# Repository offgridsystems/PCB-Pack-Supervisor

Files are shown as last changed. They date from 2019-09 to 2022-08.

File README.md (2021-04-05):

# Pack Supervisor
### Hardware Files For The 127x97mm Pack Supervisor Board
These are the printed circuit board (PCB) files, CAD files, specification sheets and all technical drawings needed to make the DKblock Pack Supervisor board. Note that the bill of materials (BOM) and other technical documents can be opened in [OpenOffice](https://www.openoffice.org) format and PCB files are in [EAGLE](https://www.autodesk.com/products/eagle/overview) format but they can also be opened and edited in the open source Kicad program.

#### VERSIONS
- Rev A - Revision A (retired name of board is Supervisor LV Rev A)  is a fully tested board, put into  production on a 72VDC electric scooter named Fido, and a 150VDC VW bug conversion.
- Rev B - Revision B are design files that make improvements on the A version, and change the board name to Pack Supervisor 97x127mm Rev B, but *Rev B has neither not been built nor tested in the real world*. Note that most of the changes are minor and are simple tweaks to improve performance or reliability.
- Ver 2 - NOT RELEASED but these are improvements to cost, performance, and reliability.

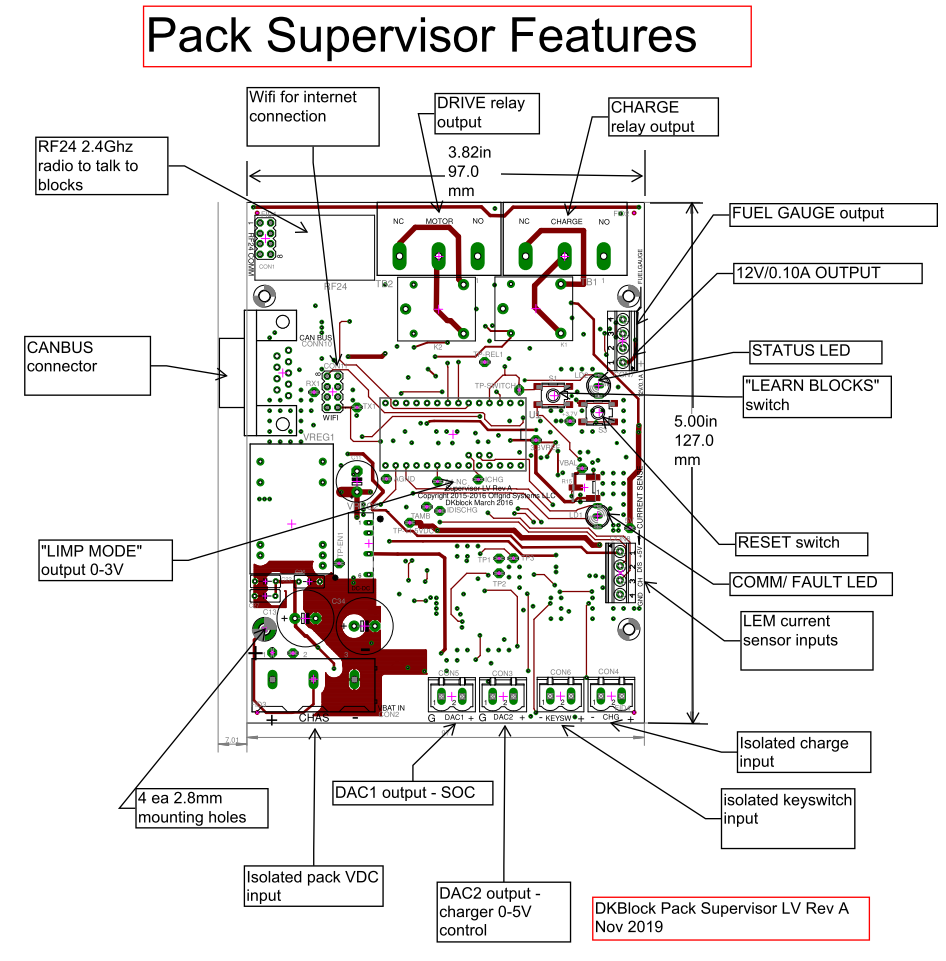
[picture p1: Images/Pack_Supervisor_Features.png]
Pack Supervisor Features


Pack Supervisor Top RevA

Pack Supervisor Bottom RevA

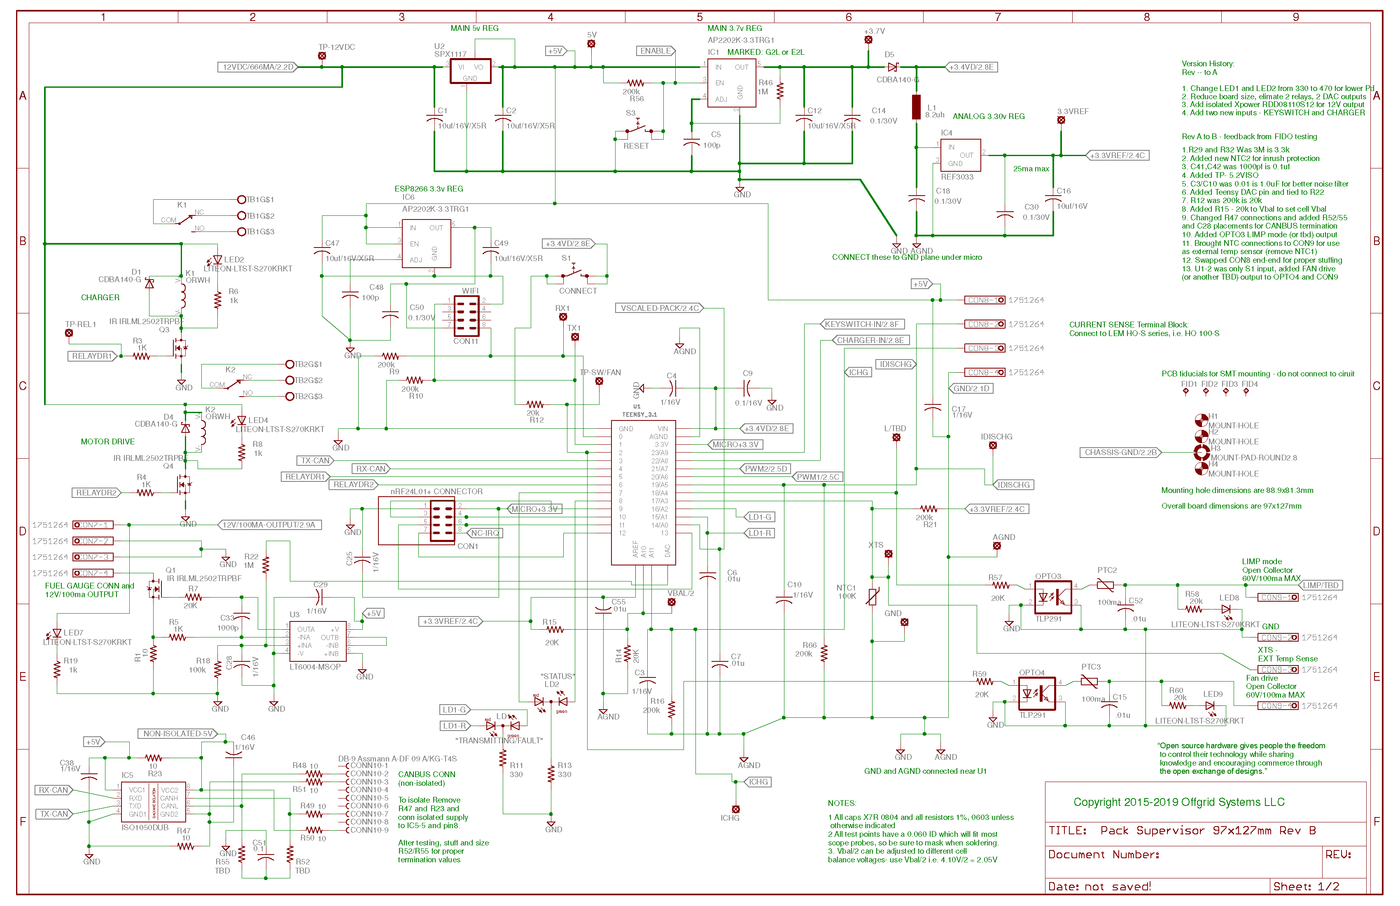
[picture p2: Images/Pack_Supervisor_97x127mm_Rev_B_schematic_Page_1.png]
Pack Supervisor Schematic 1


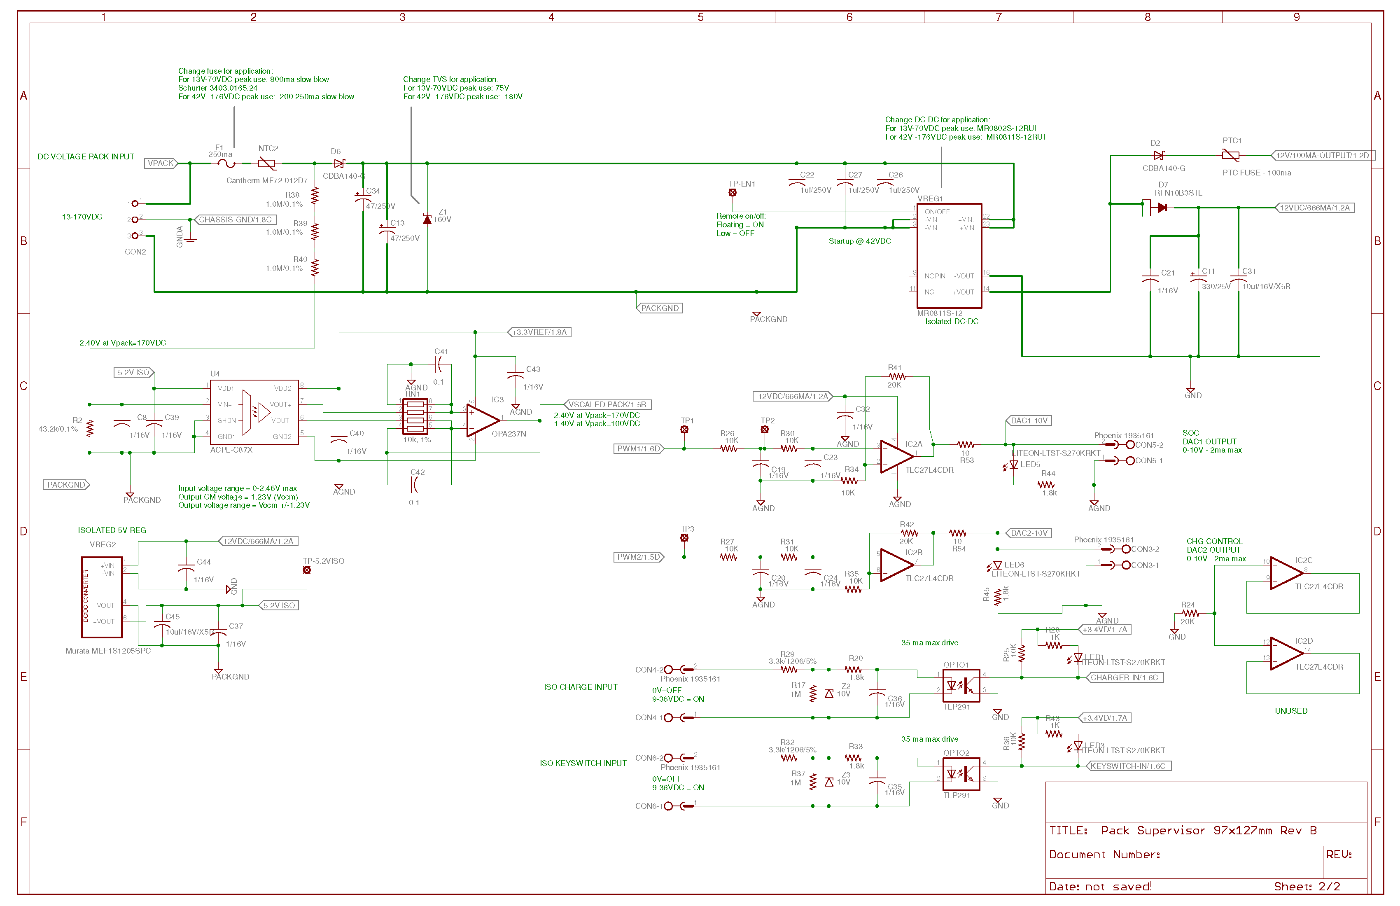
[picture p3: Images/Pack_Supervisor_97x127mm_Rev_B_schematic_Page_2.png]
Pack Supervisor Schematic 1


New V2 radio (replaces RF24 board and requires new Supervisor V2 firmware)



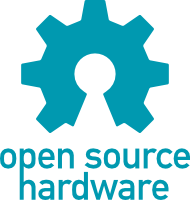
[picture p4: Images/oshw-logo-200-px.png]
Open Hardware


All DKblock software and hardware is released as open source hardware (OSHW) as defined by the OSHWA: https://www.oshwa.org/definition/ and under the JSON license defined at https://www.json.org/license.html

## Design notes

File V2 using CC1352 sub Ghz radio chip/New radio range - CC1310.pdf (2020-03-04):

Sheet1

Page 1

## New radio range – cc1310 using two CC1310 Lauchpads and TI SmartRF studio

Test conditions, Cow hill lab, TX/RX set at 50kbps, 2-GFSK, 25kHz deviation for most of testing, also tested at 500kBps,

### 175khz dev with no real changes, both CC1310 Lauchpad units had low cost PCB antenna

Freq (Mhz) TX power dBm RX @1 meter range(dBm) 9 meter range | notes
750 | 14 | -32 | -52 | all RX is at 0.0% PER and 0.00% Bit error rate and tested at 50k-500kBPS no discernable receive signal loss
850 -20
868 | | -20 | -49
950 -32
1000 | | -39 | -70 | Would go from -70 to -80 by just walking around room between TX and RX units
1100 -50
868 | -10 | | -72
868 OFF | | | -93

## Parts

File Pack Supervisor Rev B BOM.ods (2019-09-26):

Pack Supervisor BOM Rev B |  |  | Offgrid Systems | 05/12/16 | Rev --7/1/2015 for changes from assy feedback, Rev A 5/12/2016 new smaller board with more features – built 10 pcs at TASC in seattle
 |  |  |  | 04/17/17 | Rev B -Changes based on testing Rev A
 |  |  |  |  |  |  |  |  |  | Circuit ok
x=Offgrid Provided |  |  | DNS = Do not stuff (on VREG1 please mask PCB pins) |  |  |  |  |  |  | New part size
 |  |  |  |  |  |  |  |  |  | Double check BOM
 | Qty | Value | Device | Package | Parts | Description | 100PCPRICE | Ext 100 | MPN (all in stock at Digikey) | Double check BOM | PIN-HEADER | Alternative PN
 | 7 | STATUS | LEDSMT | 2 SMD | LED1, LED2, LED3, LED4, LED5, LED6, LED7 | LED YELLOW CLEAR 0603 R/A SMD | 0.103 | 0.721 | LiteOn LTST-S270KSKT | x
 | 2 | STATUS & TRANSMITTING | Radial - 3 Lead | Radial 3 | LD1, LD2 | LED 5MM BI-COLOR RED/GRN DIFF | 0.2 | 0.4 | Kingbright WP59EGC
 |  |  |  |  |  |  |  | 0
 | 9 | 10 | R-US_R0603 | R0603 | R1, R23, R47, R48, R49, R50, R51, R53, R54 | RES SMD 10 OHM 1% 1/10W 0603 | 0.018 | 0.162 | Bourns CR0603-FX-10R0ELF
 | 2 | 330 | R-US_R0603 | R0603 | R11, R13 | RES SMD 330 OHM 1% 1/10W 0603 | 0.0187 | 0.0374 | Bourns CR0603-FX-3300ELF
 | 8 | 1k | R-US_R0603 | R0603 | R3, R4, R5, R6, R8, R19, R28, R43 | RES SMD 1K OHM 1% 1/10W 0603 | 0.018 | 0.144 | Bourns CR0603-FX-1001ELF
 | 4 | 1.8k | R-US_R0603 | R0603 | R20, R33, R44, R45 | RES SMD 1.8K OHM 1% 1/10W 0603 | 0.018 | 0.072 | CR0603-FX-1801ELF
 | 8 | 10k | R-US_R0603 | R0603 | R25, R26, R27, R30, R31, R34, R35, R36 | RES SMD 10K OHM 1% 1/10W 0603 | 0.018 | 0.144 | Bourns CR0603-FX-1002ELF
 | 5 | 20k | R-US_R0603 | R0603 | R7, R14, R24, R41, R42 | RES SMD 20K OHM 1% 1/10W 0603 | 0.018 | 0.09 | Bourns CR0603-FX-2002ELF
 | 1 | 43.2k/0.1% | R-US_R0603 | R0603 | R2 | RES SMD 43.2KOHM 0.1% 1/10W 0603 | 0.192 | 0.192 | Panasonic ERA-3AEB4322V
 | 1 | 100K | R-US_R0603 | R0603 | R18 | RES SMD 100K OHM 1% 1/10W 0603 | 0.018 | 0.018 | Bourns CR0603-FX-1003ELF
 | 7 | 200k | R-US_R0603 | R0603 | R9, R10, R12, R16, R21, R56, R66 | RES SMD 200K OHM 1% 1/10W 0603 | 0.018 | 0.126 | Bourns CR0603-FX-2003ELF
 | 4 | 1M | R-US_R1206 | R1206 | R17, R22, R37, R46 | RES SMD 1M OHM 1% 1/10W 0603 | 0.0187 | 0.0748 | Bourns CR0603-FX-1004ELF
 | 3 | 1.0M/0.1% | R0805 | R0805 | R38, R39, R40 | RES SMD 1M OHM 0.1% 1/8W 0805 | 0.192 | 0.576 | Panasonic ERA-6AEB105V
 | 2 | 3M/1206/5% | R-US_R1206 | R1206 | R29, R32 | RES SMD 3M OHM 5% 1/4W 1206 | 0.015 | 0.03 | Panasonic ERJ-8GEYJ305V
 | 1 | 10k | 1206 | 1206 | RN1 | RES ARRAY 4 RES 10K OHM 1206 5% | 0.023 | 0.023 | Yageo TC164-FR-0710KL | x |  | Yageo TC164-FR-0710KL
 | 2 | 100p | C-USC0805K | C0805K | C5, C48 | CAP CER 100PF 50V 10% X7R 0805 | 0.079 | 0.158 | Kemet C0805C101K5RACTU
 | 1 | 1000p | C-USC0805K | C0805K | C33 | CAP CER 1000PF 50V 10% X7R 0805 | 0.017 | 0.017 | Kemet C0805C102K5RACTU
 | 6 | .01u | c0805 | c0805 | C3, C6, C7, C10, C15, C55 | CAP CER 10000PF 50V 10% X7R 0805 | 0.015 | 0.09 | Kemet C0805C103K5RACTU
 | 7 | 0.1/50V | c0805 | c0805 | C14, C18, C9, C30, C50, C41, C42 | CAP CER 0.1UF 50V 10% X7R 0805 | 0.022 | 0.154 | Kemet C0805C104K5RACTU
 | 21 | 1/16V | C-USC0805K | C0805K | C4, C8, C17, C19, C20, C21, C23, C24, C25, C28, CONT. BELOW | CAP CER 1UF 16V 10% X7R 0805 | 0.04 | 0.84 | Kemet C0805C105K4RACTU
 |  |  |  |  | C29, C32, C35, C36, C37, C38, C39, C40, C43, C44, C46 |  |  | 0
 | 3 | 1uf/250V | Radial 2 lead .2in | Radial 2 | C22, C26, C27 | CAP CER 1UF 20% 250V X7R Thru hole | 0.833 | 2.499 | MURATA RDER72E105MUB1H03B | x
 | 8 | 10uf/16V/X5R | C-USC0805K | C0805K | C1, C2, C12, C16, C31, C45, C47, C49 | CAP CER 10UF 16V 20% X5R 0805 | 0.062 | 0.496 | Murata GRM21BR61C106ME15L
 | 2 | 47/250V | CPOL-USE5-13 | E5-13 | C13, C34 | CAP ALUM 47UF 250V 20% RADIAL | 0.508 | 1.016 | PANASONIC ECA-2EM470
 | 1 | 330uf | Radial 2 lead | 0.315" Dia | C11 | CAP ALUM 330UF 25V 20% Radial | 0.216 | 0.216 | United Chemicon EKY-250ELL331MJC5S
 |  |  |  |  |  |  |  | 0
 | 1 | 250ma SB | UMT250 | UMT250 | F1 | FUSE BRD MNT 250MA 250VAC 125VDC | 0.51 | 0.51 | Schurter 3403.0160.11 | x |  | Schurter 3403.0159 or Schurter 3403.0161
 | 1 | 100ma PTC fuse | 0603 | 0603 | PTC1 | PTC RESETTBLE 0.10A 15V CHIP 0603 | 0.11 | 0.11 | Bel Fuse 0ZCM0010FF2G
 | 1 | 1A 12 ohm NTC | Power NTC | 9mm leaded | NTC2 | ICL, 12 ohm, 20% 1A 9mm dia, leaded | 0.22 | 0.22 | Cantherm MF72-012D7
 |  |  |  |  |  |  |  | 0
 | 1 | 100K | NTC-MURATA-NCP18WF104J03RB | 0603 | NTC1 | THERMISTOR NTC 100K OHM 5% 0603 | 0.106 | 0.106 | MURATA NCP18WF104J03RB
 |  |  |  |  |  |  |  | 0
 | 1 | 8.2uh | SM-1206 | SM-1206 | L1 | FIXED IND 8.2UH 25MA 800 MOHM | 0.22 | 0.22 | Abracon AIML-1206-8R2K-T
 |  |  |  |  |  |  |  | 0
 | 1 | RFN10B3STL | RFN10B3STL | TO252-FATPADS | D7 | DIODE GEN PURP 350V 10A CPD | 0.59 | 0.59 | ROHM RFN10B3STL
 | 2 | ZENER – 10V | SOT23 | SOT23 | Z2, Z3 | DIODE ZENER 10V 225MW SOT23-3 | 0.084 | 0.168 | ON SEMI SZBZX84C10LT1G | x
 | 5 | CDBA140-G | CDBA140-G | DO214AC | D1, D2, D4, D5, D6 | DIODE SCHOTTKY 40V 1A DO214AC | 0.187 | 0.935 | Comchip CDBA140-G
 | 1 | ZENER – 160V | SMB | SMB | Z1 | DIODE ZENER 160V 3W SMB | 0.218 | 0.218 | ON SEMI 1SMB5954BT3G | x
 |  |  |  |  |  |  |  | 0
 | 2 | CONNECT and RESET | PTS645 | PTS645 | S1, S3 | SWITCH TACTILE SPST-NO 0.05A 12V | 0.129 | 0.258 | C&k PTS645SM43SMTR92 LFS
 |  |  |  |  |  |  |  | 0
 | 3 | IRLML2502TRPBF | SOT23 | SOT23 | Q1, Q3, Q4 | MOSFET N-CH 20V 4.2A SOT-23 | 0.22 | 0.66 | IR IRLML2502TRPBF
 |  |  |  |  |  |  |  | 0
 | 2 | Current sensors & Fuel Gauge connectors | 1751264 | 1751264 | CON7, CON8 | CONN TERM BLOCK 4POS 3.5MM 300V 10A | 2 | 4 | Phoenix 1751264
 | 2 | TE-5-1437652-4 | TE-5-1437652-4 | TE-5-1437652-4 | TB1, TB2 | Connector Barrier Block Strip 3 Circuit 0.375" 300V 25A | 1.16 | 2.32 | TE 5-1437652-4
 | 4 | Phoenix Term block | 2 Pos 0.197” pitch |  | CON3, CON4, CON5, CON6 | TERM BLOCK PCB 2POS 5.0MM GREEN | 0.327 | 1.308 | Phoenix 1935161 | x
 | 1 | TYCO-796739-3 | TYCO-796739-3 | TYCO-796739-3 | CON2 | TERM BLOCK 3POS SIDE ENT 9.52MM | 3.22 | 3.22 | TE 796739-3
 | 1 | WIFI | DUAL ROW 0.1X0.1 |  | CON11 | 8 Position Header Connector 0.100" 2x4 | 0.52 | 0.52 | Sullins PPPC042LFBN-RC | x
 | 1 | CON1 socket for RF24 | Female socket header | female socket | CON1 | 8 Position Header Connector 0.100" 2x4 | 0.52 | 0.52 | Sullins PPPC042LFBN-RC | x
 |  |  |  |  |  |  |  | 0
 | 1 | ACPL-C87X | STRETCH-SO8 | STRETCH-SO8 | U4 | IC OPAMP ISOLATION 100KHZ 8SO | 5.71 | 5.71 | Avago ACPL-C87B-000E | x
 | 2 | TLP291 | MINI FLAT 4 | MINI FLAT 4 | OPTO1, OPTO2 | OPTOISOLATOR 3.75KV TRANS 4-SO | 0.332 | 0.664 | Toshiba TLP291(BLL-TP,SE | x
 | 1 | REF3033 | SOT23 | SOT23 | IC4 | IC VREF SERIES 3.3V SOT23-3 | 1.18 | 1.18 | TI REF3033AIDBZR | x
 | 1 | MEF1S1205 | 7-SIP Module (4 Leads) |  | VREG2 | DC/DC CONVERTER 5V 1W SIP | 4.6 | 4.6 | Murata MEF1S1205SPC | x
 | 1 | OPA237 | SOT23-5 | SOT23-5 | IC3 | IC OPAMP GP 1.5MHZ SOT23-5 | 1.06 | 1.06 | TI OPA237NA/3K | x
 | 1 | LT6004 | MSOP | MSOP | U3 | IC OPAMP GP 3KHZ RRO 8MSOP | 1.3 | 1.3 | LTC LT6004CMS8 | x
 | 1 | ISO1050 | 8sop |  | IC5 | IC TXRX CAN 5V 8SOP | 3.43 | 3.43 | TI ISO1050DUBR | x
 | 2 | AP2202K-3.3TRG1 | MIC5205 | SOT23-5 | IC1, IC6 | IC REG LDO 3.3V 0.15A SOT25 | 0.19 | 0.38 | Diodes AP2202K-3.3TRG1
 | 1 | SPX1117 | SPX1117 | SOT223 | U2 | IC REG LDO 5V 0.8A SOT223 | 0.26 | 0.26 | Exar SPX1117M3-L-5-0/TR
 | 1 | TLC27L4CDR | TLC27L4CDR | SO14 | IC2 | IC OPAMP Low IQ RRO 14SOIC | 0.63 | 0.63 | TI TLC27L4CDR
 | 1 | U1 socket – stuff in all 31 positions of U1 |  |  | IC1 – all 31 positions | Connector Socket 60 Position 0.100" (2.54mm) Gold Through Hole |  | 0 | Precidip 315-87-160-41-003101 (need 6 ea for every 10 PCB)
x | 1 | MR0811s-12 | Leaded CAN |  | VREG1 | Ultra-wide input DC/DC DIP case 12V outpuy | 17 | 17 | MicroPower Direct MR0811S-12RUI |  |  | Xppower RDD08110S12
 | 2 | ORWH | ORWH | ORWH | K1, K2 | RELAY GEN PURPOSE SPDT 10A 12V 277V/28VDC switch | 0.653 | 1.306 | TE 1461069-5 |  |  | TE ORWH-SH-112D,N000
x | 1 | DSUB-9 | Dsub |  | CONN10 | 9 Pos D-Sub Male Pins Connector, TH, RA Solder | 0.56 | 0.56 | ASSMANN A-DS 09 A/KG-T4S
 | 1 | PCB |  |  |  | PCB, Supervisor LV Rev A | 5 | 5 | Offgrid Supervisor LV Rev A PCB
 |  |  |  |  |  | total dk part cost |  | 67.2592
 |  | Note to PCB Assembly house - DO NOT STUFF these parts – they will be added by hand after PCB assembly phase
x | 1 | Teensy 3.1 without pins | TEENSY_3.0-DIP+ANALOG | TEENSY_3.0-DIP+ANALOG | U1 | Do NOT STUFF – U1 only stuff socket | 15 | #VALUE! | OshPark Teensy 3.1 or Addcore Teensy 3.1
x | 1 | Addicore nRF24l01+ | RF24 board |  | CON1 transceiver | nRF24l01 2.4Mhz transceiver | 1 |  | Addicore nRF24l01+
 | 4 | standoff |  |  |  | BRD SPT REST MNT SNAP LOCK 3/16" |  |  | Keystone 9056
 | 1 for every 2 PCBs |  |  |  | U1 Teensy pins for sockets – solder onto Teensy board | Precision pins 0.018 dia for socketizing |  |  | Mill max 342-10-164-00-591000

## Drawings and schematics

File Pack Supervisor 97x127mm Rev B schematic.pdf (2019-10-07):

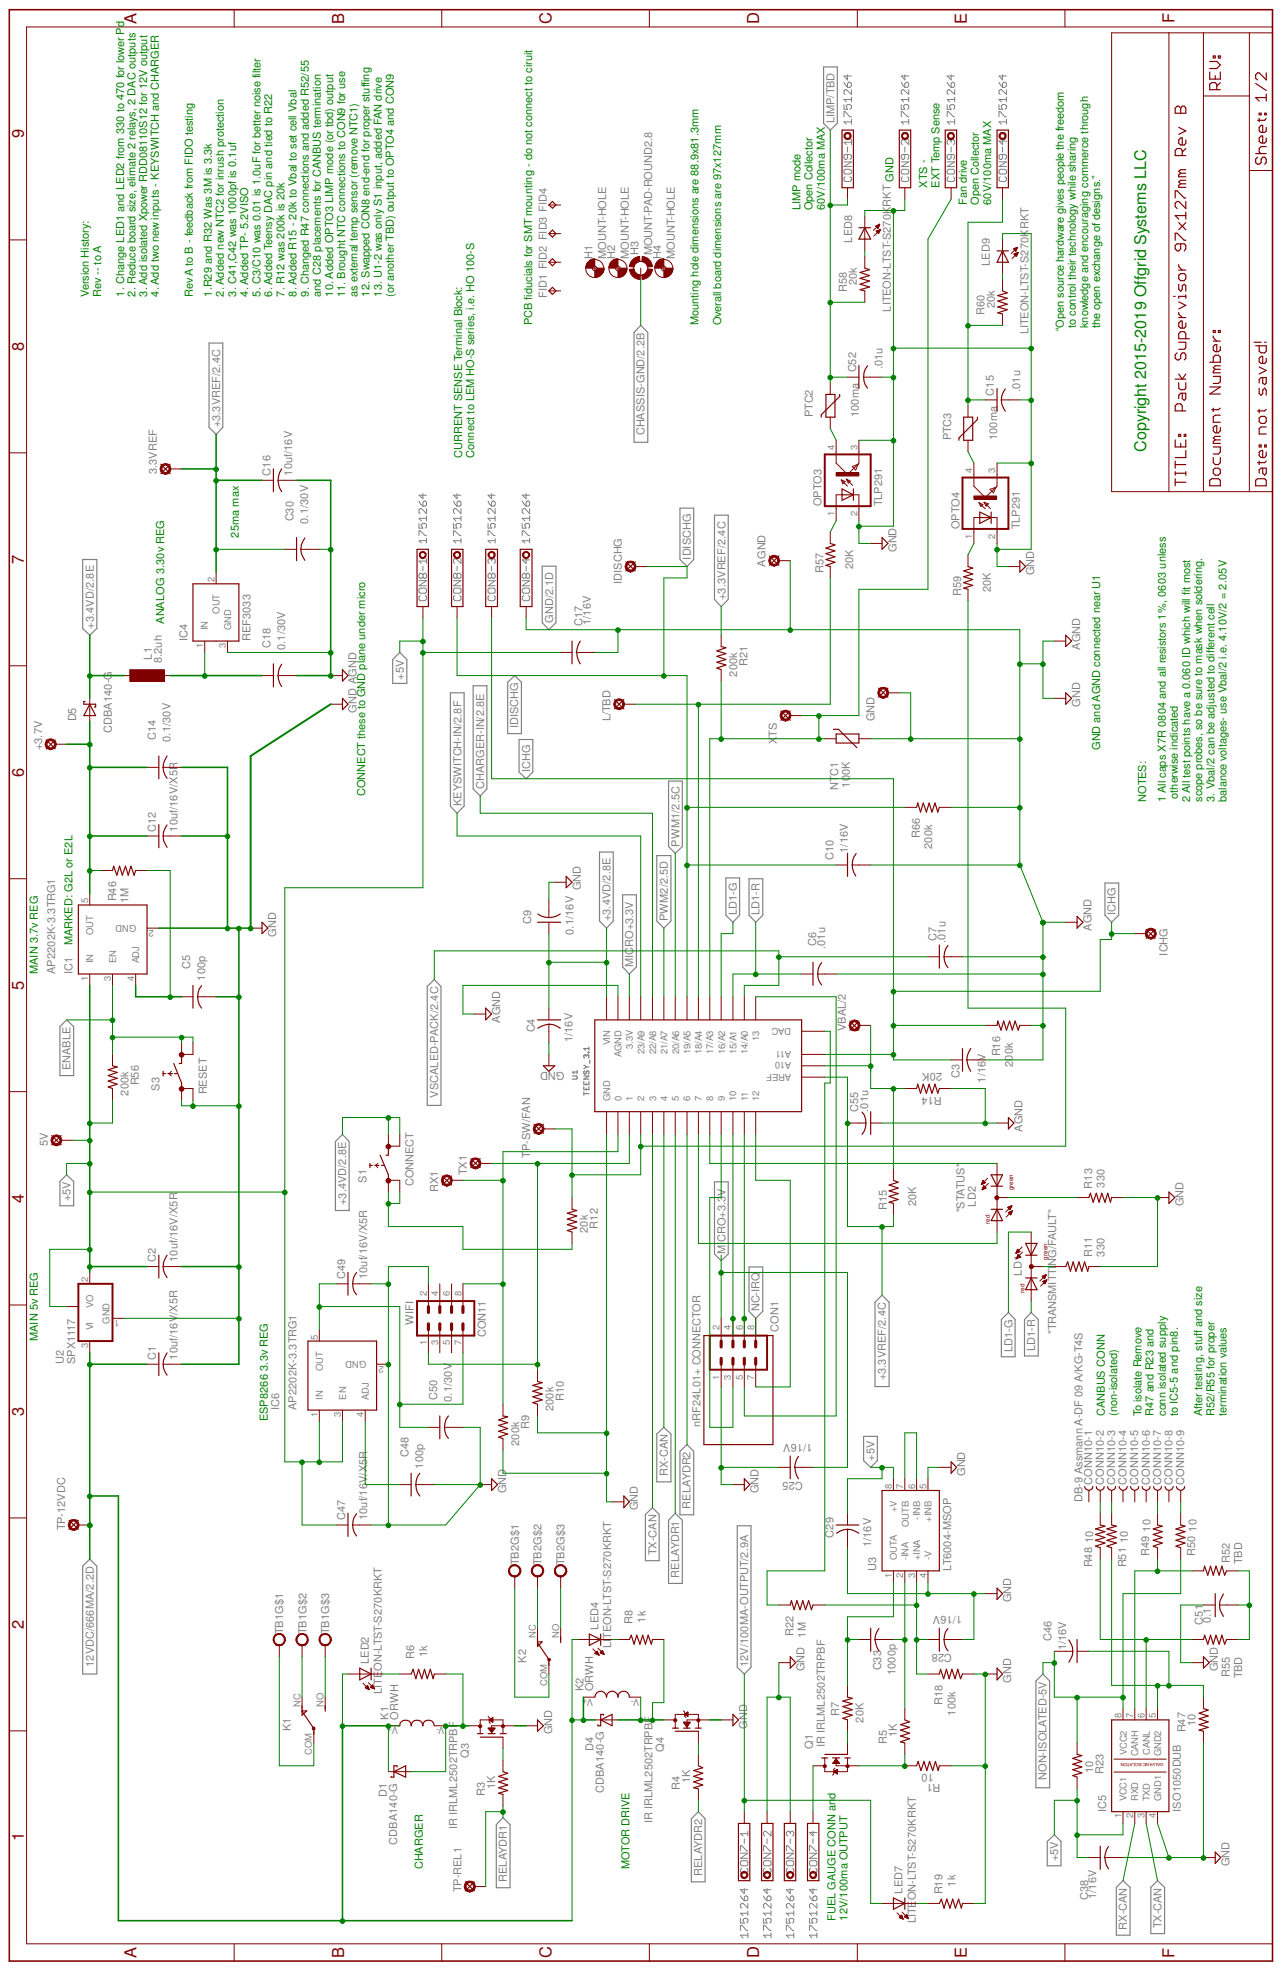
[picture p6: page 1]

1. Change LED1 and LED2 from 330 to 470 for lower Pd

2. Reduce board size, elimate 2 relays, 2 DAC outputs

3. Add isolated Xpower RDD08110S12 for 12V output

4. Add two new inputs - KEYSWITCH and CHARGER

PCB fiducials for SMT mounting - do not connect to ciruit

5. C3/C10 was 0.01 is 1.0uF for better noise filter

9. Changed R47 connections and added R52/55

12. Swapped CON8 end-end for proper stuffing

and C28 placements for CANBUS termination

10. Added OPTO3 LIMP mode (or tbd) output

11. Brought NTC connections to CON9 for use

13. U1-2 was only S1 input, added FAN drive

(or another TBD) output to OPTO4 and CON9

6. Added Teensy DAC pin and tied to R22

8. Added R15 - 20k to Vbal to set cell Vbal

“Open source hardware gives people the freedom

Rev A to B - feedback from FIDO testing

2. Added new NTC2 for inrush protection

as external temp sensor (remove NTC1)

Mounting hole dimensions are 88.9x81.3mm

knowledge and encouraging commerce through

Overall board dimensions are 97x127mm

to control their technology while sharing

the open exchange of designs.”

Connect to LEM HO-S series, i.e. HO 100-S

CURRENT SENSE Terminal Block:

1 All caps X7R 0804 and all resistors 1%, 0603 unless

2 All test points have a 0.060 ID which will fit most

scope probes, so be sure to mask when soldering.

balance voltages- use Vbal/2 i.e. 4.10V/2 = 2.05V

GND and AGND connected near U1

CONNECT these to GND plane under micro

3. Vbal/2 can be adjusted to different cell

MAIN 5v REG MAIN 3.7v REG

After testing, stuff and size

DB-9 Assmann A-DF 09 A/KG-T4S

FUEL GAUGE CONN and

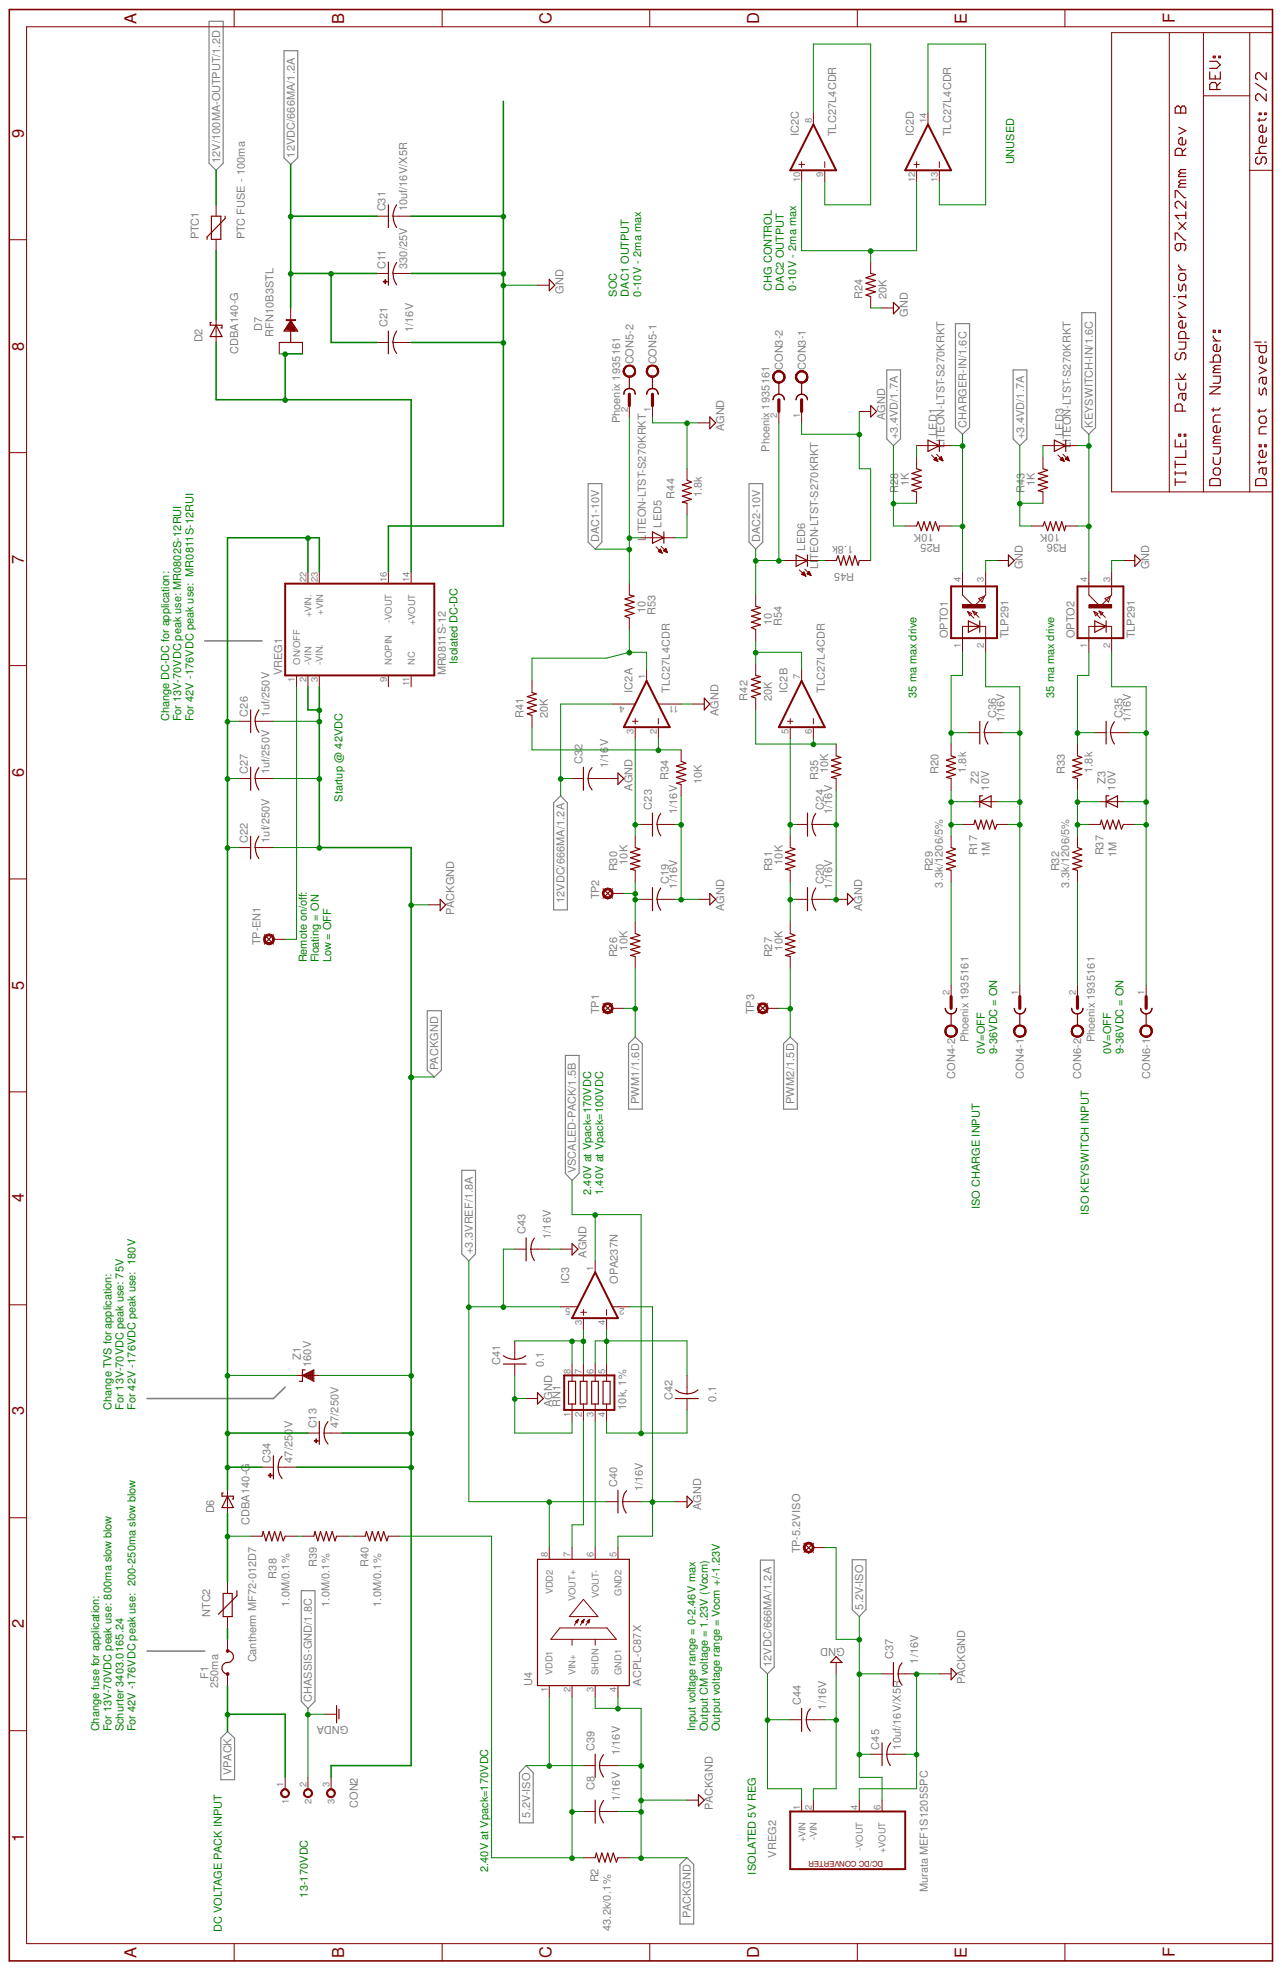
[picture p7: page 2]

Change DC-DC for application:

Change TVS for application:

For 42V -176VDC peak use: 200-250ma slow blow

For 13V-70VDC peak use: 800ma slow blow

Output voltage range = Vocm +/-1.23V

Output CM voltage = 1.23V (Vocm)

Input voltage range = 0-2.46V max

Change fuse for application:

DC VOLTAGE PACK INPUT

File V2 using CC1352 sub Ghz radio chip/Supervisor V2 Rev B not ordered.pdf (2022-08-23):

A

A

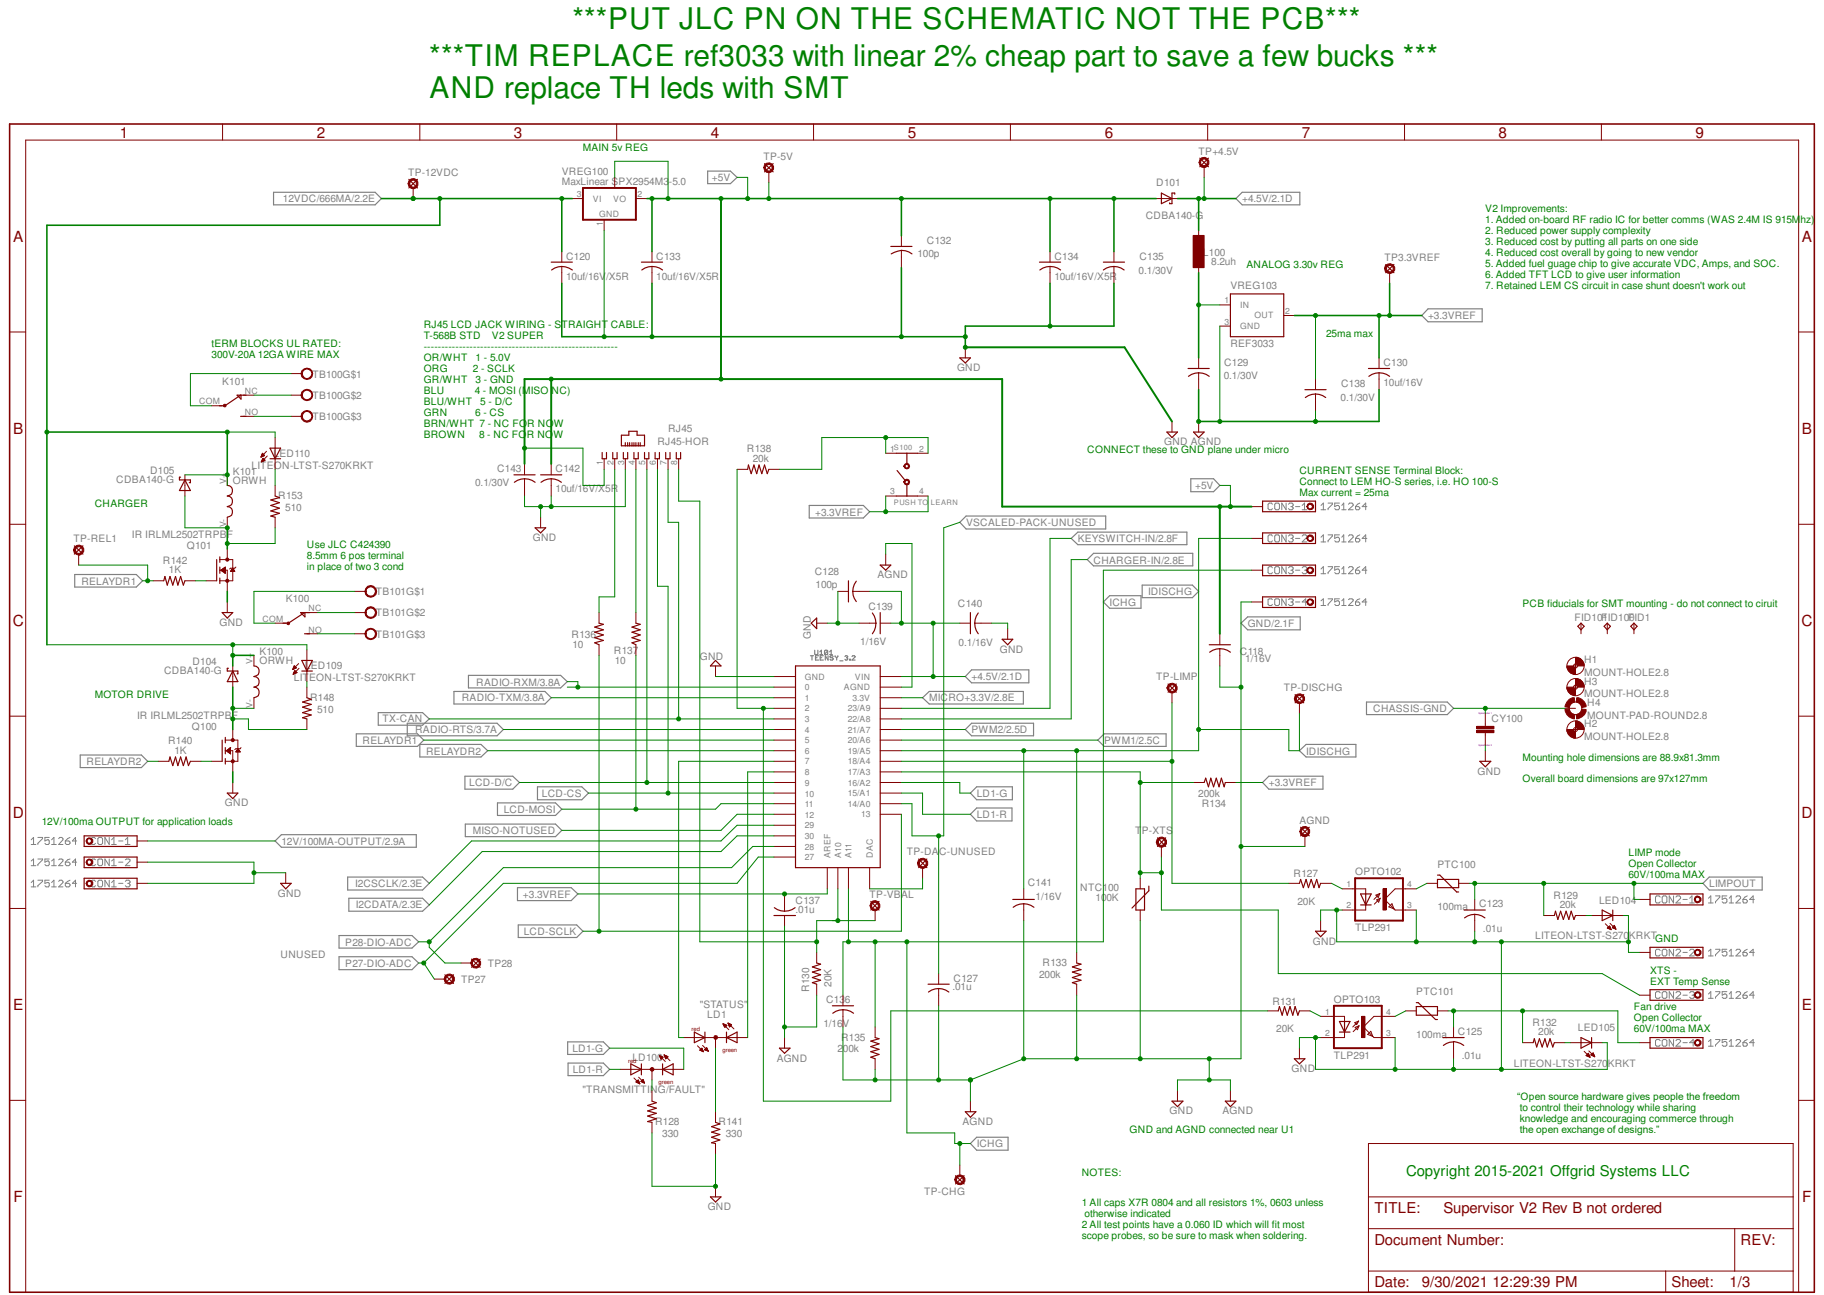
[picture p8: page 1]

***PUT JLC PN ON THE SCHEMATIC NOT THE PCB***

***TIM REPLACE ref3033 with linear 2% cheap part to save a few bucks ***
AND replace TH leds with SMT

V2 Improvements:
1. Added on-board RF radio IC for better comms (WAS 2.4M IS 915Mhz)
2. Reduced power supply complexity
3. Reduced cost by putting all parts on one side
4. Reduced cost overall by going to new vendor
5. Added fuel guage chip to give accurate VDC, Amps, and SOC.
6. Added TFT LCD to give user information
7. Retained LEM CS circuit in case shunt doesn't work out

RJ45 LCD JACK WIRING - STRAIGHT CABLE:
T-568B STD V2 SUPER ------------------------------------------------------- OR/WHT 1 - 5.0V

tERM BLOCKS UL RATED:
300V-20A 12GA WIRE MAX

GR/WHT 3 - GND
BLU/WHT 5 - D/C
BRN/WHT 7 - NC FOR NOW

CONNECT these to GND plane under micro

CURRENT SENSE Terminal Block:
Connect to LEM HO-S series, i.e. HO 100-S
Max current = 25ma

Use JLC C424390
8.5mm 6 pos terminal
in place of two 3 cond

PCB fiducials for SMT mounting - do not connect to ciruit

Mounting hole dimensions are 88.9x81.3mm

Overall board dimensions are 97x127mm

12V/100ma OUTPUT for application loads

“Open source hardware gives people the freedom
to control their technology while sharing
knowledge and encouraging commerce through
the open exchange of designs.”

GND and AGND connected near U1

Copyright 2015-2021 Offgrid Systems LLC

1 All caps X7R 0804 and all resistors 1%, 0603 unless
otherwise indicated
2 All test points have a 0.060 ID which will fit most
scope probes, so be sure to mask when soldering.

Supervisor V2 Rev B not ordered

Document Number: | REV:

Date: 9/30/2021 12:29:39 PM | Sheet: 1/3

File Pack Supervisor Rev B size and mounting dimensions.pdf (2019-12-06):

97

88.87

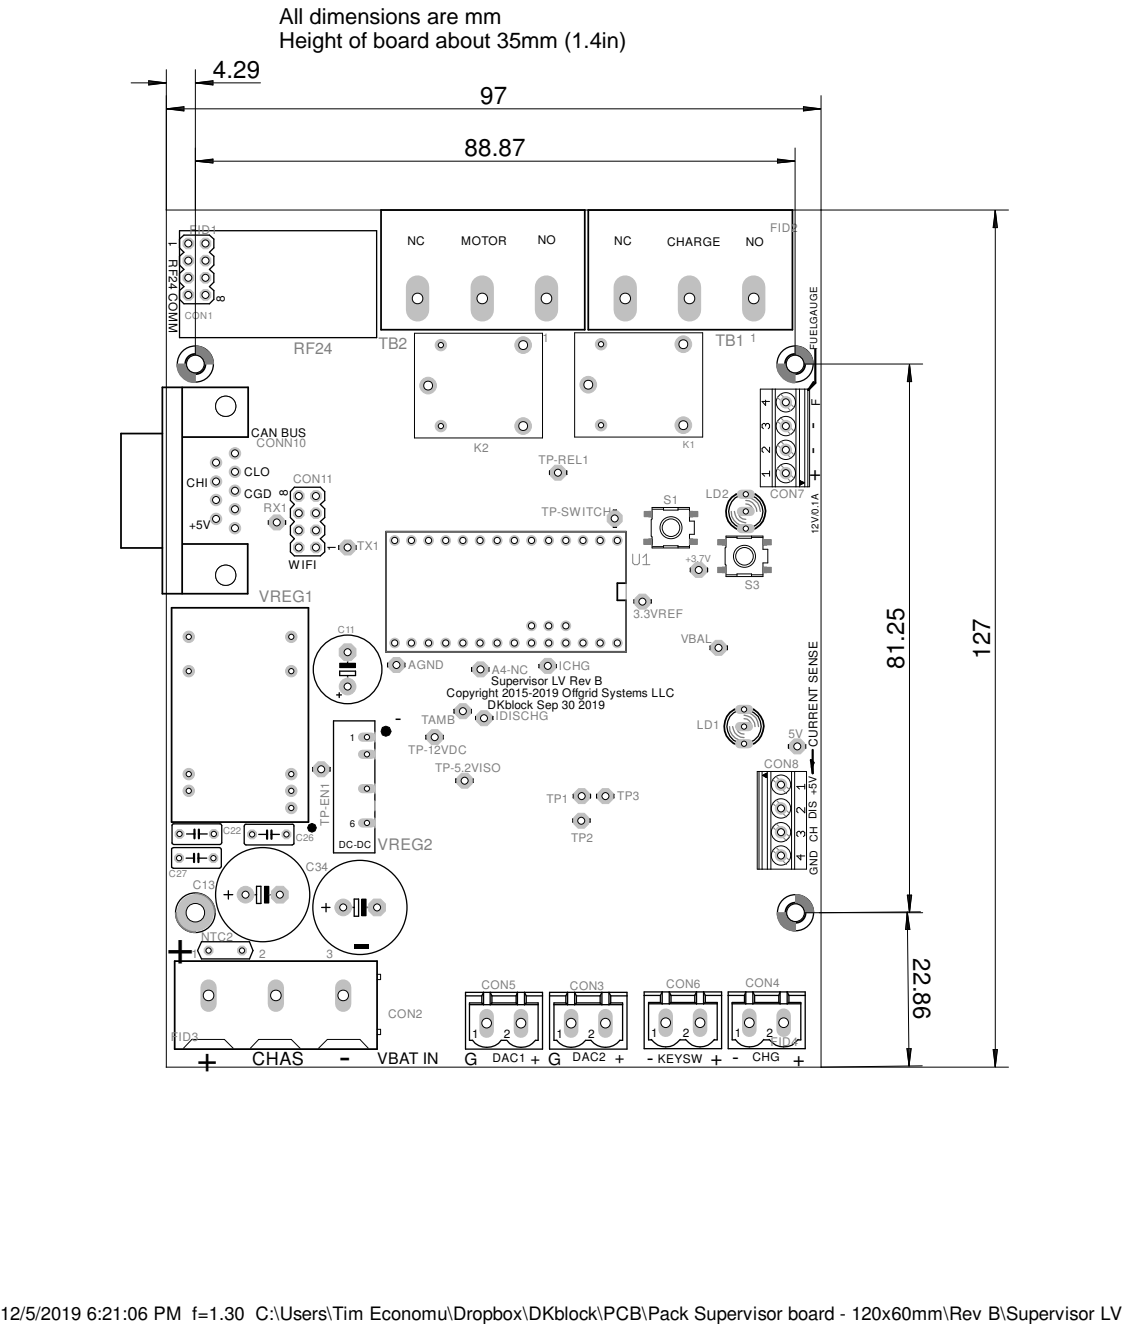
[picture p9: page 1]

All dimensions are mm
Height of board about 35mm (1.4in)

12/5/2019 6:21:06 PM f=1.30 C:\Users\Tim Economu\Dropbox\DKblock\PCB\Pack Supervisor board - 120x60mm\Rev B\Supervisor LV Rev B.brd

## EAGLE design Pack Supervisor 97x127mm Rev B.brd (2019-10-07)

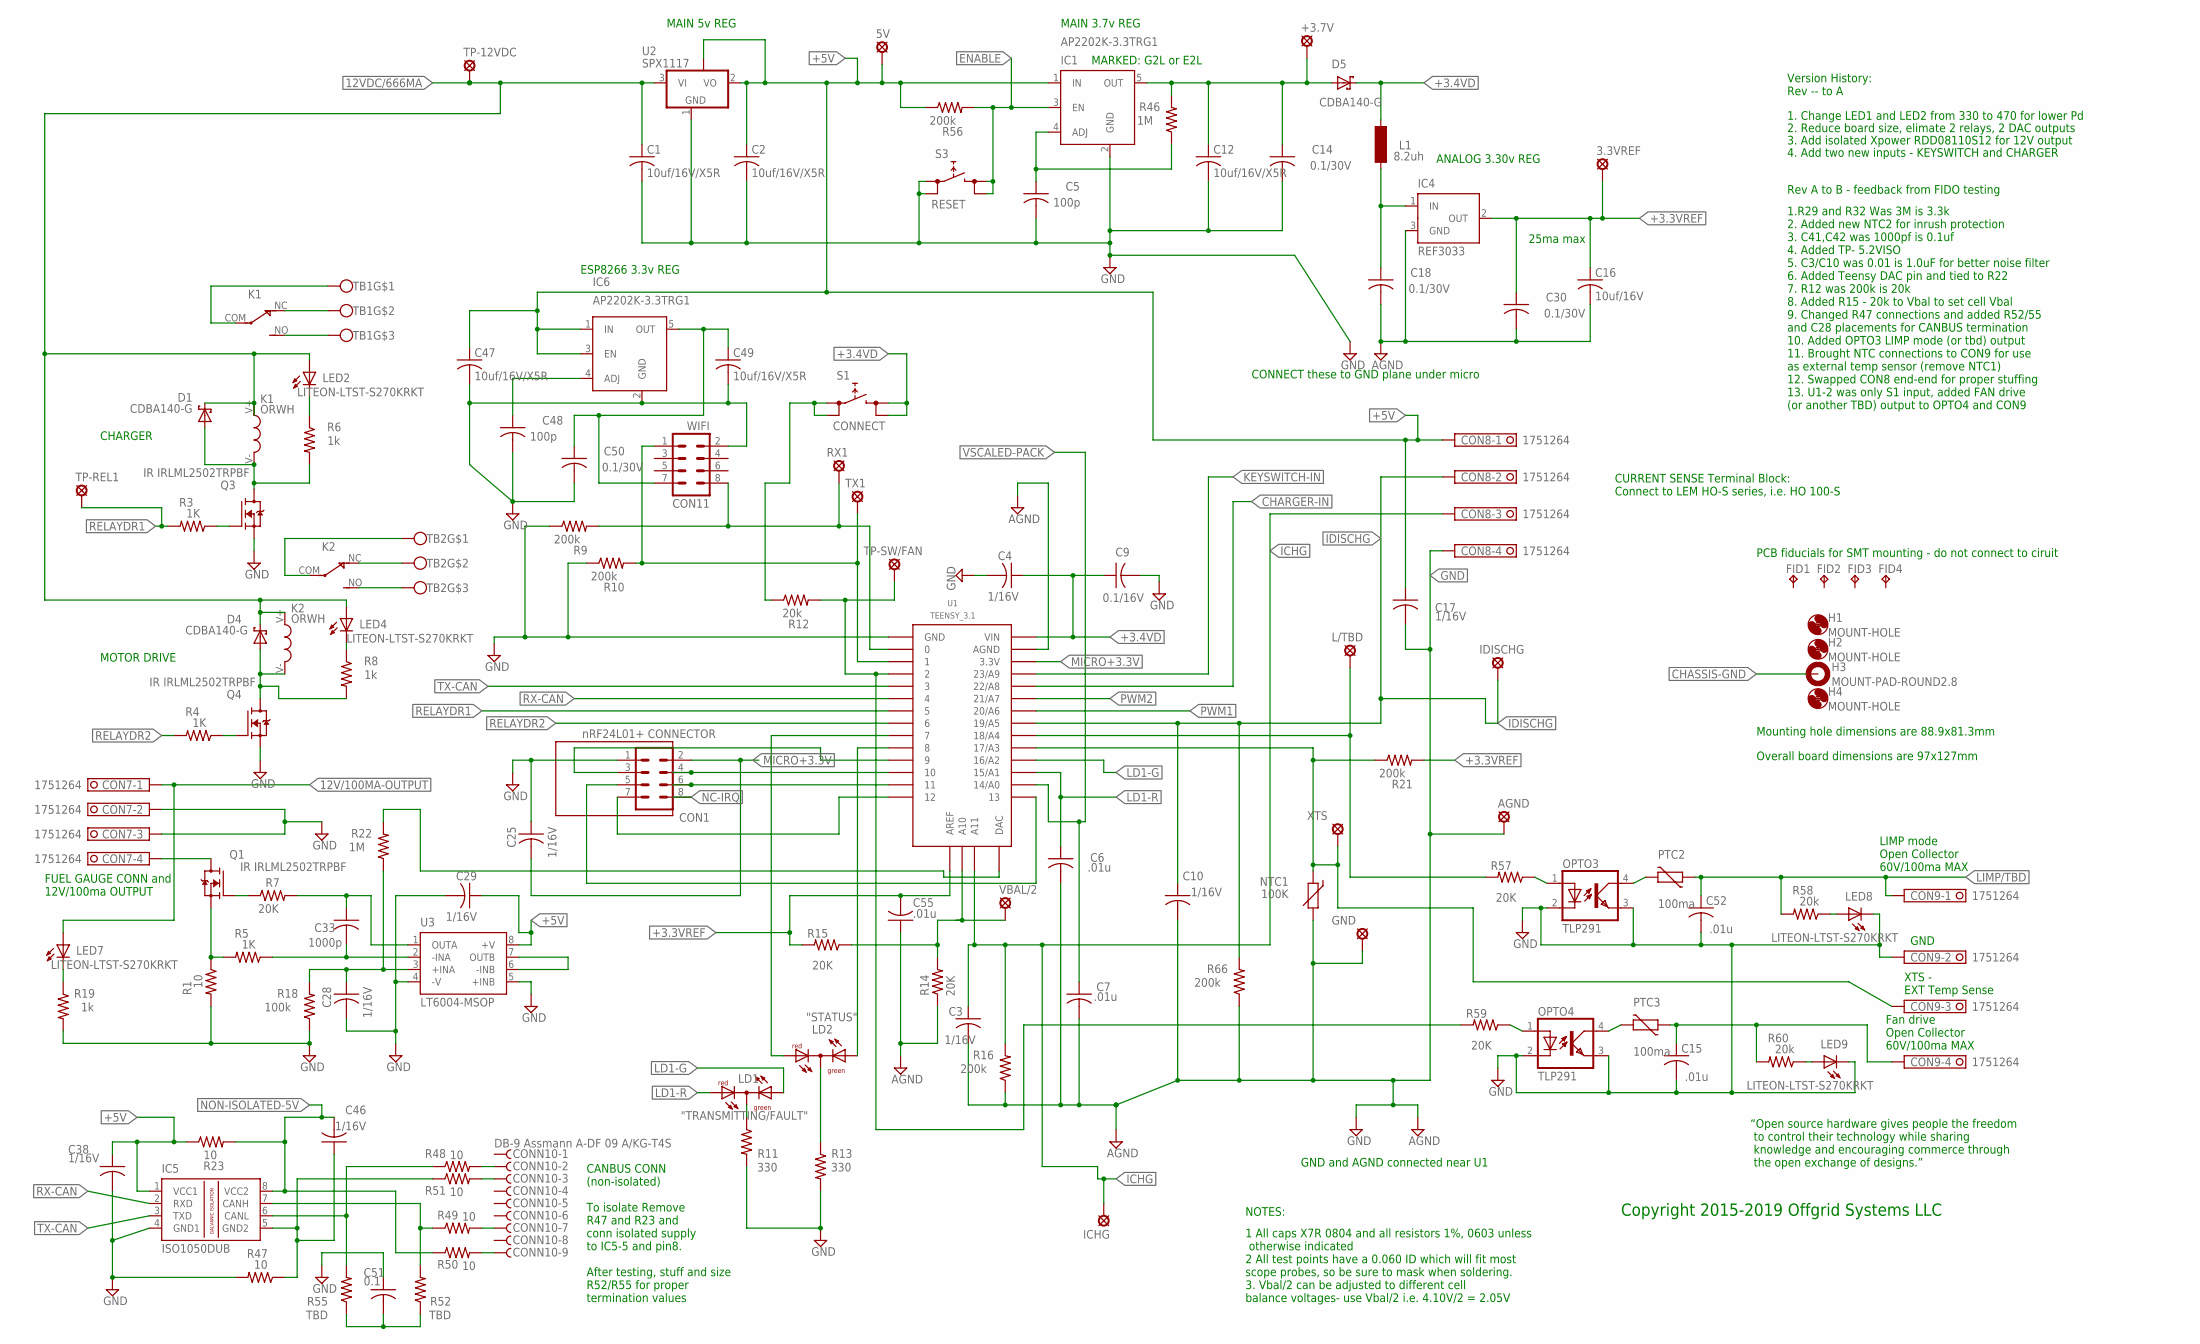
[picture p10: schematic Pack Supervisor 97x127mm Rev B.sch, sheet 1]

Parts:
3.3VREF, 5V: LSP10
+3.7V: LSP10
AGND: LSP10
C1, C2, C12, C47, C49: 10uf/16V/X5R; C0805K; MPN Murata GRM21BR61C106ME15L
C3, C10: 1/16V; TIMS_INDUCTOR_C0805; MPN Kemet C0805C103K5RACTU
C4, C17, C25, C28, C29, C38, C46: 1/16V; TIMS_INDUCTOR_C0805; MPN Kemet C0805C105K4RACTU
C5, C48: 100p; TIMS_INDUCTOR_C0805; MPN Kemet C0805C104K5RACTU
C6, C7, C15, C52: .01u; TIMS_INDUCTOR_C0805; MPN Kemet C0805C103K5RACTU
C9: 0.1/16V; TIMS_INDUCTOR_C0805; MPN Kemet C0805C104K5RACTU
C14, C18, C30, C50: 0.1/30V; TIMS_INDUCTOR_C0805; MPN Kemet C0805C104K5RACTU
C16: 10uf/16V; C0805K; MPN Murata GRM21BR61A476ME15L
C33: 1000p; TIMS_INDUCTOR_C0805; MPN Kemet C0805C105K4RACTU
C51: 0.1; TIMS_INDUCTOR_C0805; MPN Kemet C0805C105K4RACTU
C55: .01u; C0805; MPN Welwyn PCF0603R-3K01BT1
CON1: nRF24L01+ CONNECTOR; NRF24L01
CON7, CON8, CON9: 1751264
CON11: WIFI; MA04-2; MPN Sullins PPPC042LFBN-RC
CONN10: DB-9 Assmann A-DF 09 A/KG-T4S; H5M09RA; MPN ASSMANN A-DS 09 A/KG-T4S
D1, D4, D5: CDBA140-G; DO214AC; MPN comchip CDBA140-G
FID1, FID2, FID3, FID4: FIDUCIALTP10R; TP10R
GND: LSP10
H1: MOUNT-HOLE; 2,6; MPN Keystone 9056
H2, H4: MOUNT-HOLE; 2,6
H3: MOUNT-PAD-ROUND2.8; 2,8-PAD
IC1, IC6: AP2202K-3.3TRG1; SOT23-5; MPN Diodes AP2202K-3.3TRG1
IC4: REF3033; SOT23; MPN TI REF3033AIDBZR
IC5: ISO1050DUB; DUB-R-PDSO-G8; MPN TI ISO1050DUBR
ICHG: LSP10
IDISCHG: LSP10
K1, K2: ORWH; MPN TE 1461069-5
L1: 8.2uh; SM-1206; MPN Abracon AIML-1206-8R2K-T
L/TBD: LSP10
LD1: "TRANSMITTING/FAULT"; DUOLED-C-5MM; MPN Kingbright WP59EGC
LD2: "STATUS"; DUOLED-C-5MM; MPN Kingbright WP59EGC
LED2, LED4, LED7, LED8, LED9: LITEON-LTST-S270KRKT; MPN LiteOn LTST-S270KSKT
NTC1: 100K; 0603; MPN MURATA NCP18WF104J03RB
OPTO3, OPTO4: TLP291; MINI-FLAT-4
PTC2, PTC3: 100ma; CT/CN0603; MPN Bel Fuse 0ZCM0010FF2G
Q1, Q3, Q4: IRLML2502TRPBF; SOT23; MPN IR IRLML2502TRPBF
R1, R23, R47, R48, R49, R50, R51: 10; R0603; MPN Bourns CR0603-FX-10R0ELF
R3, R4, R5: 1K; R0603; MPN Bourns CR0603-FX-1001ELF
R6, R8, R19: 1k; R0603; MPN Bourns CR0603-FX-3300ELF
R7, R14, R15, R57, R59: 20K; R0603; MPN Bourns CR0603-FX-2002ELF
R9, R10, R16, R21, R56, R66: 200k; R0603; MPN Bourns CR0603-FX-2003ELF
R11, R13: 330; R0603; MPN Bourns CR0603-FX-3300ELF
R12: 20k; R0603; MPN Bourns CR0603-FX-2003ELF
R18: 100k; R0603; MPN Bourns CR0603-FX-1003ELF
R22, R46: 1M; R0603; MPN Bourns CR0603-FX-1004ELF
R52, R55: TBD; 0207/5V
R58, R60: 20k; R0603; MPN Bourns CR0603-FX-1001ELF
RX1: LSP10
S1: CONNECT; PTS645; MPN C&k PTS645SM43SMTR92 LFS
S3: RESET; PTS645; MPN C&k PTS645SM43SMTR92 LFS
TB1, TB2: TE-5-1437652-4; MPN TE 5-1437652-4
TP-12VDC: LSP10
TP-REL1: LSP10
TP-SW/FAN: LSP10
TX1: LSP10
U1: TEENSY_3.1; TEENSY_3.0-DIP+ANALOG+DAC; MPN OshPark Teensy 3.1
U2: SPX1117; SOT223; MPN Exar SPX1117M3-L-5-0/TR
U3: LT6004-MSOP; MPN LTC LT6004CMS8
VBAL/2: LSP10
XTS: LSP10

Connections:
0-UNUSED: CON11.8, R9.2, RX1.MP, U1.0
5V-ESP: C49.1, C50.1, CON11.7, IC6.5 (OUT)
12V/100MA-OUTPUT: CON7.1, LED7.ANODE (A); also elsewhere on the board
12VDC/666MA: C1.1, D1.C, D4.C, K1.V+, K2.V+, LED2.ANODE (A), LED4.ANODE (A), TP-12VDC.MP, U2.3 (VI); also elsewhere on the board
+3.3VREF: 3.3VREF.MP, C16.1, C30.1, C55.2, IC4.2 (OUT), R15.2, R21.2, U1.AREF; also elsewhere on the board
+3.4VD: C4.1, C9.1, D5.C, L1.2, S1.3, S1.4, U1.VIN; also elsewhere on the board
+3.65VD: +3.7V.MP, C12.1, C14.1, D5.A, IC1.5 (OUT), R46.2
+3.300VA: C18.1, IC4.1 (IN), L1.1
+5: CONN10.9, R50.2
+5V: 5V.MP, C2.1, C17.1, C29.1, C38.1, C47.1, CON8.1, IC1.1 (IN), IC5.1 (VCC1), IC6.1 (IN), IC6.3 (EN), R23.1, R56.1, U2.2 (VO), U2.4 (TAB), U3.8 (+V)
ADC-L3: L/TBD.MP, R57.2, U1.18/A4
ADS: D4.A, K2.V-, Q4.3 (D), R8.2
CE: CON1.3, U1.9
CHARGER-IN: U1.22/A8; also elsewhere on the board
CHASSIS-GND: H3.B2,8; also elsewhere on the board
CHI: CONN10.7, R49.2
CLO: CONN10.2, R48.2
CSN: CON1.4, U1.10
DAC: R22.2, U1.14 (DAC)
ENABLE: IC1.3 (EN), R56.2, S3.3, S3.4
FAN/TBD: C15.1, CON9.4, PTC3.1, R60.2
FUELGAUGE: CON7.4, Q1.3 (D)
G: CONN10.3, R51.2
GND: AGND.MP, C1.2, C2.2, C3.2, C4.2, C5.2, C6.2, C7.2, C9.2, C10.2, C12.2, C14.2, C15.2, C16.2, C17.2, C18.2, C25.1, C28.2, C29.2, C30.2, C38.2, C47.2, C48.2, C49.2, C50.2, C51.1, C52.2, C55.1, CON1.1, CON7.2, CON7.3, CON8.4, CON9.2, CON11.2, GND.MP, IC1.2 (GND), IC4.3 (GND), IC5.4 (GND1), IC6.2 (GND), LED8.CATHODE (C), LED9.CATHODE (C), NTC1.2, OPTO3.2 (C), OPTO3.3 (EMIT), OPTO4.2 (C), OPTO4.3 (EMIT), Q3.2 (S), Q4.2 (S), R1.2, R9.1, R10.1, R11.2, R13.2, R14.1, R16.1, R18.1, R19.2, R47.2, R66.1, S3.1, S3.2, U1.AGND, U1.GND, U2.1 (GND), U3.4 (-V), U3.5 (+INB); also elsewhere on the board
ICHG: C3.1, CON8.3, ICHG.MP, R16.2, U1.A11
IDISCHG: C10.1, CON8.2, IDISCHG.MP, R66.2, U1.19/A5
KEYSWITCH-IN: U1.23/A9; also elsewhere on the board
LD1-G: LD1.AX (AG), U1.16/A2
LD1-R: C6.1, LD1.AR, U1.15/A1
LIMP/TBD: C52.1, CON9.1, PTC2.1, R58.2
MICRO+3.3V: C25.2, CON1.2, U1.3.3V
MISO: CON1.7, U1.12
MOSI: CON1.6, U1.11
unnamed: LED2.CATHODE (C), R6.1
unnamed: CON9.3, NTC1.1, R21.1, U1.17/A3, XTS.MP
unnamed: IC5.6 (CANL), R48.1, R55.2
unnamed: K1.NC, TB1.2
unnamed: D1.A, K1.V-, Q3.3 (D), R6.2
unnamed: LD2.C, R13.1
unnamed: LD2.AX (AG), U1.8
unnamed: LD2.AR, U1.7
unnamed: U3.6 (-INB), U3.7 (OUTB)
unnamed: LD1.C, R11.1
unnamed: C28.1, R18.2, R22.1, U3.3 (+INA)
unnamed: Q3.1 (G), R3.1
unnamed: IC5.7 (CANH), R49.1, R52.2
unnamed: Q4.1 (G), R4.1
unnamed: C33.1, R7.2, U3.1 (OUTA)
unnamed: C5.1, IC1.4 (ADJ), R46.1
unnamed: Q1.1 (G), R7.1
unnamed: Q1.2 (S), R1.1, R5.2
unnamed: K1.NO, TB1.3
unnamed: K1.COM, TB1.1
unnamed: K2.COM, TB2.1
unnamed: K2.NC, TB2.2
unnamed: C33.2, R5.1, U3.2 (-INA)
unnamed: K2.NO, TB2.3
unnamed: LED4.CATHODE (C), R8.1
unnamed: C46.1, IC5.5 (GND2), R47.1, R51.1
unnamed: R12.2, R59.2, TP-SW/FAN.MP, U1.2
unnamed: C51.2, R52.1, R55.1
unnamed: CON11.1, R10.2, TX1.MP, U1.1
unnamed: LED7.CATHODE (C), R19.1
unnamed: C48.1, IC6.4 (ADJ)
unnamed: LED8.ANODE (A), R58.1
unnamed: OPTO3.1 (A), R57.1
unnamed: OPTO3.4 (COL), PTC2.2
unnamed: LED9.ANODE (A), R60.1
unnamed: OPTO4.1 (A), R59.1
unnamed: OPTO4.4 (COL), PTC3.2
unnamed: R12.1, S1.1, S1.2
NC-IRQ: CON1.8
NON-ISOLATED-5V: C46.2, IC5.8 (VCC2), R23.2, R50.1
PWM1: U1.20/A6; also elsewhere on the board
PWM2: U1.21/A7; also elsewhere on the board
RELAYDR1: R3.2, TP-REL1.MP, U1.5
RELAYDR2: R4.2, U1.6
RX-CAN: IC5.2 (RXD), U1.4
SCK: CON1.5, U1.13
TX-CAN: IC5.3 (TXD), U1.3
VBAL: R14.2, R15.1, U1.A10, VBAL/2.MP
VSCALED-PACK: C7.1, U1.14/A0; also elsewhere on the board

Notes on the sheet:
Copyright 2015-2019 Offgrid Systems LLC
GND and AGND connected near U1
NOTES:
1 All caps X7R 0804 and all resistors 1%, 0603 unless otherwise indicated 2 All test points have a 0.060 ID which will fit most scope probes, so be sure to mask when soldering. 3. Vbal/2 can be adjusted to different cell balance voltages- use Vbal/2 i.e. 4.10V/2 = 2.05V
Version History: Rev -- to A
CONNECT these to GND plane under micro
PCB fiducials for SMT mounting - do not connect to ciruit
1. Change LED1 and LED2 from 330 to 470 for lower Pd
2. Reduce board size, elimate 2 relays, 2 DAC outputs
3. Add isolated Xpower RDD08110S12 for 12V output
4. Add two new inputs - KEYSWITCH and CHARGER
25ma max
MAIN 5v REG
MAIN 3.7v REG
ANALOG 3.30v REG
ESP8266 3.3v REG
FUEL GAUGE CONN and 12V/100ma OUTPUT
CANBUS CONN (non-isolated) To isolate Remove R47 and R23 and conn isolated supply to IC5-5 and pin8. After testing, stuff and size R52/R55 for proper termination values
CURRENT SENSE Terminal Block: Connect to LEM HO-S series, i.e. HO 100-S
Rev A to B - feedback from FIDO testing
1.R29 and R32 Was 3M is 3.3k 2. Added new NTC2 for inrush protection 3. C41,C42 was 1000pf is 0.1uf 4. Added TP- 5.2VISO 5. C3/C10 was 0.01 is 1.0uF for better noise filter 6. Added Teensy DAC pin and tied to R22 7. R12 was 200k is 20k 8. Added R15 - 20k to Vbal to set cell Vbal 9. Changed R47 conn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
MOTOR DRIVE
CHARGER
Mounting hole dimensions are 88.9x81.3mm
“Open source hardware gives people the freedom to control their technology while sharing knowledge and encouraging commerce through the open exchange of designs.”
Overall board dimensions are 97x127mm
MARKED: G2L or E2L
LIMP mode Open Collector 60V/100ma MAX
XTS - EXT Temp Sense
GND
Fan drive Open Collector 60V/100ma MAX

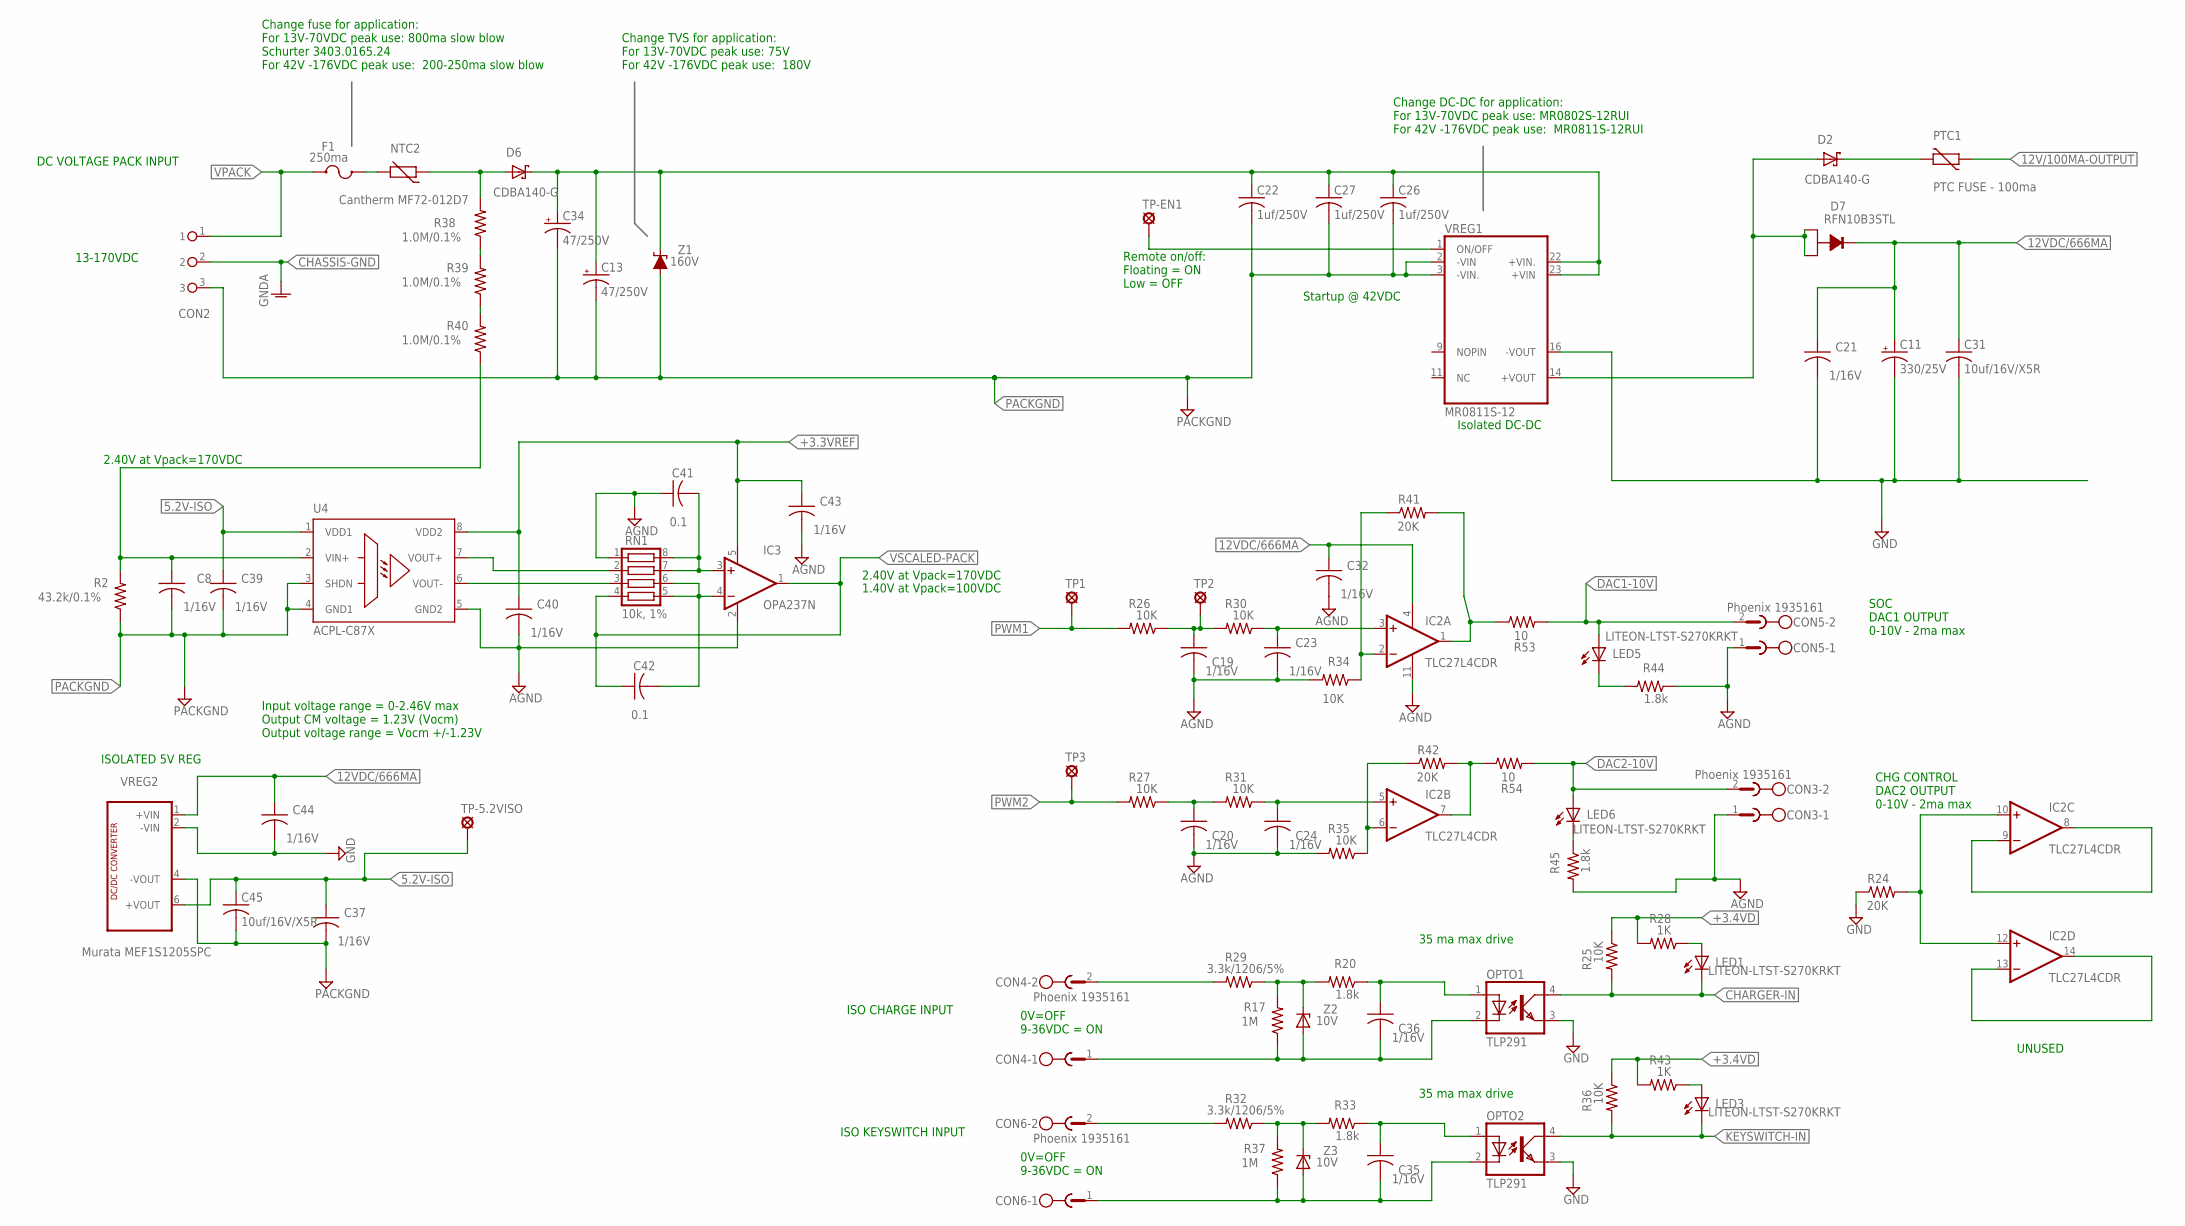
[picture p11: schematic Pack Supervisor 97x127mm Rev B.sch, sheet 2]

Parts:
C8, C19, C20, C21, C23, C24, C32, C35, C36, C37, C39, C40, C43, C44: 1/16V; TIMS_INDUCTOR_C0805; MPN Kemet C0805C105K4RACTU
C11: 330/25V; E5-10,5
C13, C34: 47/250V; E5-13; MPN PANASONIC ECA-2EM470
C22, C26, C27: 1uf/250V; RCL_C050-030X075
C31, C45: 10uf/16V/X5R; C0805K; MPN Murata GRM21BR61C106ME15L
C41, C42: 0.1; TIMS_INDUCTOR_C0805; MPN Kemet C0805C105K4RACTU
CON2: TYCO-796739-3
CON3, CON4, CON5, CON6: Phoenix 1935161; MSTBV2; MPN Phoenix 1935161
D2, D6: CDBA140-G; DO214AC; MPN comchip CDBA140-G
D7: RFN10B3STL; TO252-FATPADS; MPN ROHM RFN10B3STL
F1: 250ma; SCHURTER-UMT250; MPN Schurter 3403.0159.24
IC2: TLC27L4CDR; SO14; MPN TI TLC27L4CDR
IC3: OPA237N; SOT23-5; MPN TI OPA237NA/3K
LED1, LED3, LED5, LED6: LITEON-LTST-S270KRKT; MPN LiteOn LTST-S270KSKT
NTC2: Cantherm MF72-012D7; D7-PACKAGE
OPTO1, OPTO2: TLP291; MINI-FLAT-4
PTC1: PTC FUSE - 100ma; CT/CN0603; MPN Bel Fuse 0ZCM0010FF2G
R2: 43.2k/0.1%; R0603; MPN Panasonic ERA-3AEB4322V
R17, R37: 1M; R0603; MPN Bourns CR0603-FX-1004ELF
R20, R33, R44, R45: 1.8k; R0603; MPN Bourns CR0603-FX-1821ELF
R24, R41, R42: 20K; R0603; MPN Bourns CR0603-FX-2002ELF
R25, R26, R27, R30, R31, R34, R35, R36: 10K; R0603; MPN Bourns CR0603-FX-1002ELF
R28, R43: 1K; R0603; MPN Bourns CR0603-FX-1001ELF
R29, R32: 3.3k/1206/5%; R1206; MPN Panasonic ERJ-8GEYJ305V
R38, R39, R40: 1.0M/0.1%; R0805; MPN Panasonic ERA-6AEB105V
R53, R54: 10; R0603; MPN Bourns CR0603-FX-10R0ELF
RN1: 10k, 1%; CTS742C083; MPN Yageo TC164-FR-0710KL
TP1, TP2, TP3: LSP10
TP-5.2VISO: LSP10
TP-EN1: LSP10
U4: ACPL-C87X; STRETCH-SO8; MPN Avago Broadcomm ACPL-C87B-000E
VREG1: MR0811S-12; MPN Micropower Direct MR0811S-12RUI
VREG2: Murata MEF1S1205SPC; MURATA-MEF; MPN Murata MEF1S1205SPC
Z1: 160V; SMB; MPN ON SEMI 1SMB5954BT3G
Z2, Z3: 10V; TIMS_DIODE_SOT23; MPN ON SEMI SZBZX84C10LT1G

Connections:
5.2V-ISO: C37.1, C39.1, C45.1, TP-5.2VISO.MP, U4.1 (VDD1), VREG2.6 (+VOUT)
12V/100MA-OUTPUT: PTC1.1; also elsewhere on the board
12VDC/666MA: C11.+, C21.1, C31.1, C32.1, C44.1, D7.DRAIN (CATHODE), IC2.4 (V+), VREG2.1 (+VIN); also elsewhere on the board
+3.3VREF: C40.1, C43.1, IC3.5 (V+), U4.8 (VDD2); also elsewhere on the board
+3.4VD: R25.1, R28.2, R36.1, R43.2; also elsewhere on the board
ASDF: IC2.1 (OUT), R41.2, R53.1
CHARGER-IN: LED1.CATHODE (C), OPTO1.4 (COL), R25.2; also elsewhere on the board
CHASSIS-GND: CON2.2; also elsewhere on the board
CHGINLO: C36.2, CON4.1, OPTO1.2 (C), R17.1, Z2.1 (A)
DAC1-10V: CON5.2, LED5.ANODE (A), R53.2
DAC2-10V: CON3.2, LED6.ANODE (A), R54.2
GND: C11.-, C19.2, C20.2, C21.2, C23.2, C24.2, C31.2, C32.2, C40.2, C41.1, C43.2, C44.2, CON3.1, CON5.1, IC2.11 (V-), IC3.2 (V-), OPTO1.3 (EMIT), OPTO2.3 (EMIT), R24.1, R34.2, R35.2, R44.1, R45.2, RN1.1, U4.5 (GND2), VREG1.16 (-VOUT), VREG2.2 (-VIN); also elsewhere on the board
KEYSWINLO: C35.2, CON6.1, OPTO2.2 (C), R37.1, Z3.1 (A)
KEYSWITCH-IN: LED3.CATHODE (C), OPTO2.4 (COL), R36.2; also elsewhere on the board
unnamed: IC2.7 (OUT), R42.2, R54.1
unnamed: R38.1, R39.2
unnamed: R39.1, R40.2
unnamed: F1.P$1 (1A), NTC2.2
unnamed: IC2.2 (-IN), R34.1, R41.1
unnamed: C23.1, IC2.3 (+IN), R30.1
unnamed: CON4.2, R29.2
unnamed: TP-EN1.MP, VREG1.1 (ON/OFF)
unnamed: C36.1, OPTO1.1 (A), R20.1
unnamed: R17.2, R20.2, R29.1, Z2.3 (C)
unnamed: IC2.6 (-IN), R35.1, R42.1
unnamed: C24.1, IC2.5 (+IN), R31.1
unnamed: C20.1, R27.1, R31.2
unnamed: IC2.8 (OUT), IC2.9 (-IN)
unnamed: IC2.13 (-IN), IC2.14 (OUT)
unnamed: IC2.10 (+IN), IC2.12 (+IN), R24.2
unnamed: LED1.ANODE (A), R28.1
unnamed: C35.1, OPTO2.1 (A), R33.1
unnamed: R32.1, R33.2, R37.2, Z3.3 (C)
unnamed: LED3.ANODE (A), R43.1
unnamed: D2.C, PTC1.2
unnamed: C19.1, R26.1, R30.2, TP2.MP
unnamed: LED5.CATHODE (C), R44.2
unnamed: LED6.CATHODE (C), R45.1
unnamed: C8.1, R2.2, R40.1, U4.2 (VIN+)
unnamed: D2.A, D7.GATE (ANODE1), D7.SOURCE (ANODE2), VREG1.14 (+VOUT)
unnamed: RN1.2, U4.7 (VOUT+)
unnamed: RN1.3, U4.6 (VOUT-)
unnamed: C42.2, IC3.4 (-IN), RN1.5, RN1.6
unnamed: C41.2, IC3.3 (+IN), RN1.7, RN1.8
unnamed: CON6.2, R32.2
PACKGND: C8.2, C13.-, C22.2, C26.2, C27.2, C34.-, C37.2, C39.2, C45.2, CON2.3, R2.1, U4.3 (SHDN), U4.4 (GND1), VREG1.2 (-VIN), VREG1.3 (-VIN.), VREG2.4 (-VOUT), Z1.A
PWM1: R26.2, TP1.MP; also elsewhere on the board
PWM2: R27.2, TP3.MP; also elsewhere on the board
TPF1A: D6.A, NTC2.1, R38.2
VIN: C13.+, C22.1, C26.1, C27.1, C34.+, D6.C, VREG1.22 (+VIN.), VREG1.23 (+VIN), Z1.C
VPACK: CON2.1, F1.P$2 (2A)
VSCALED-PACK: C42.1, IC3.1 (OUT), RN1.4; also elsewhere on the board

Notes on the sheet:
Remote on/off: Floating = ON Low = OFF
13-170VDC
Change DC-DC for application: For 13V-70VDC peak use: MR0802S-12RUI For 42V -176VDC peak use: MR0811S-12RUI
Change fuse for application: For 13V-70VDC peak use: 800ma slow blow Schurter 3403.0165.24 For 42V -176VDC peak use: 200-250ma slow blow
Change TVS for application: For 13V-70VDC peak use: 75V For 42V -176VDC peak use: 180V
2.40V at Vpack=170VDC
0V=OFF 9-36VDC = ON
35 ma max drive
Input voltage range = 0-2.46V max Output CM voltage = 1.23V (Vocm) Output voltage range = Vocm +/-1.23V
Isolated DC-DC
Startup @ 42VDC
ISO KEYSWITCH INPUT
ISO CHARGE INPUT
SOC DAC1 OUTPUT 0-10V - 2ma max
CHG CONTROL DAC2 OUTPUT 0-10V - 2ma max
UNUSED
ISOLATED 5V REG
DC VOLTAGE PACK INPUT
1.40V at Vpack=100VDC

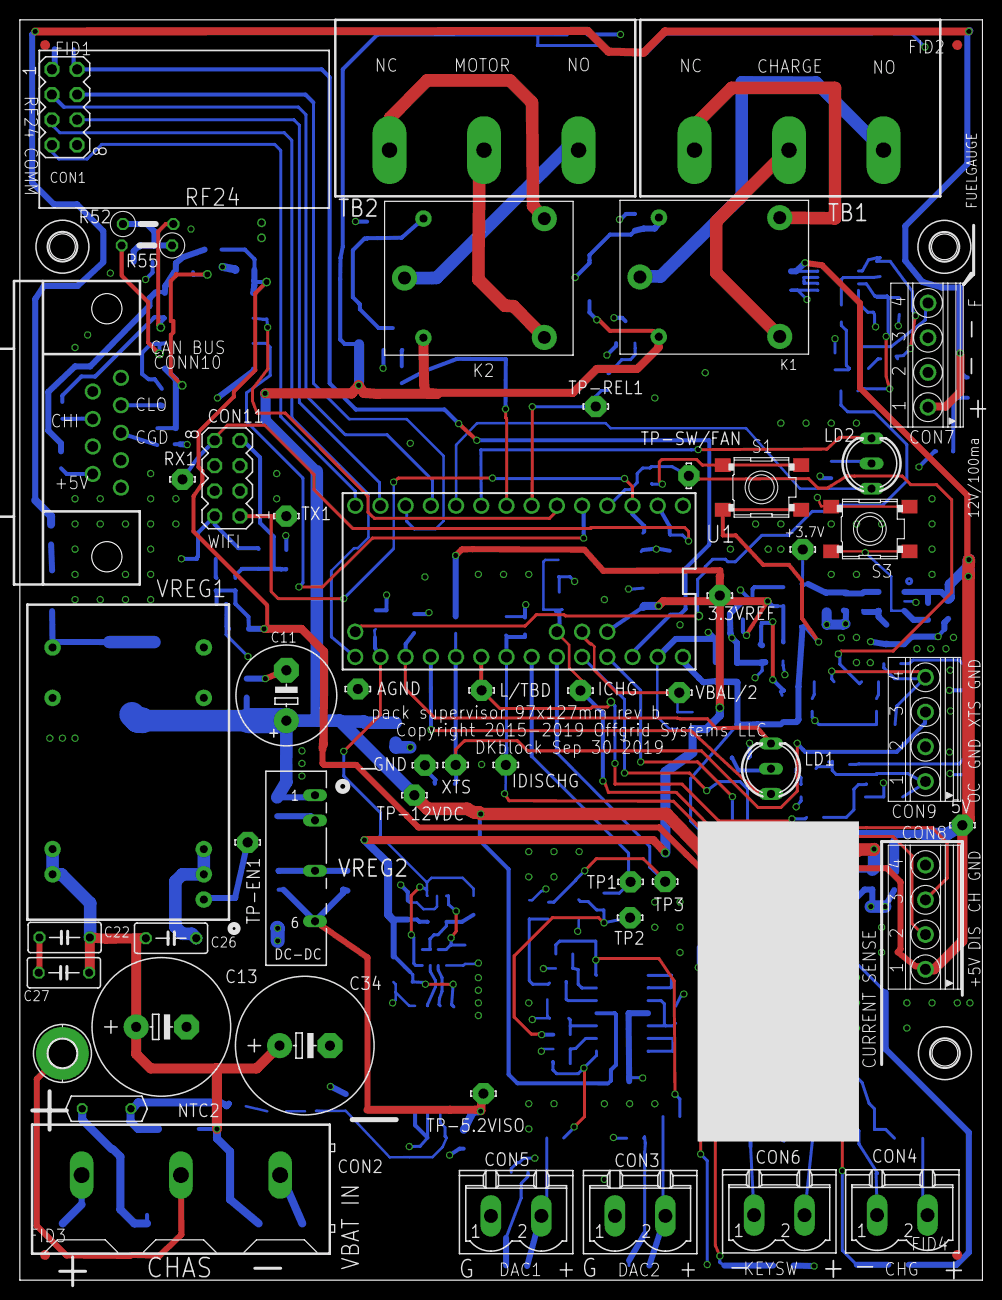
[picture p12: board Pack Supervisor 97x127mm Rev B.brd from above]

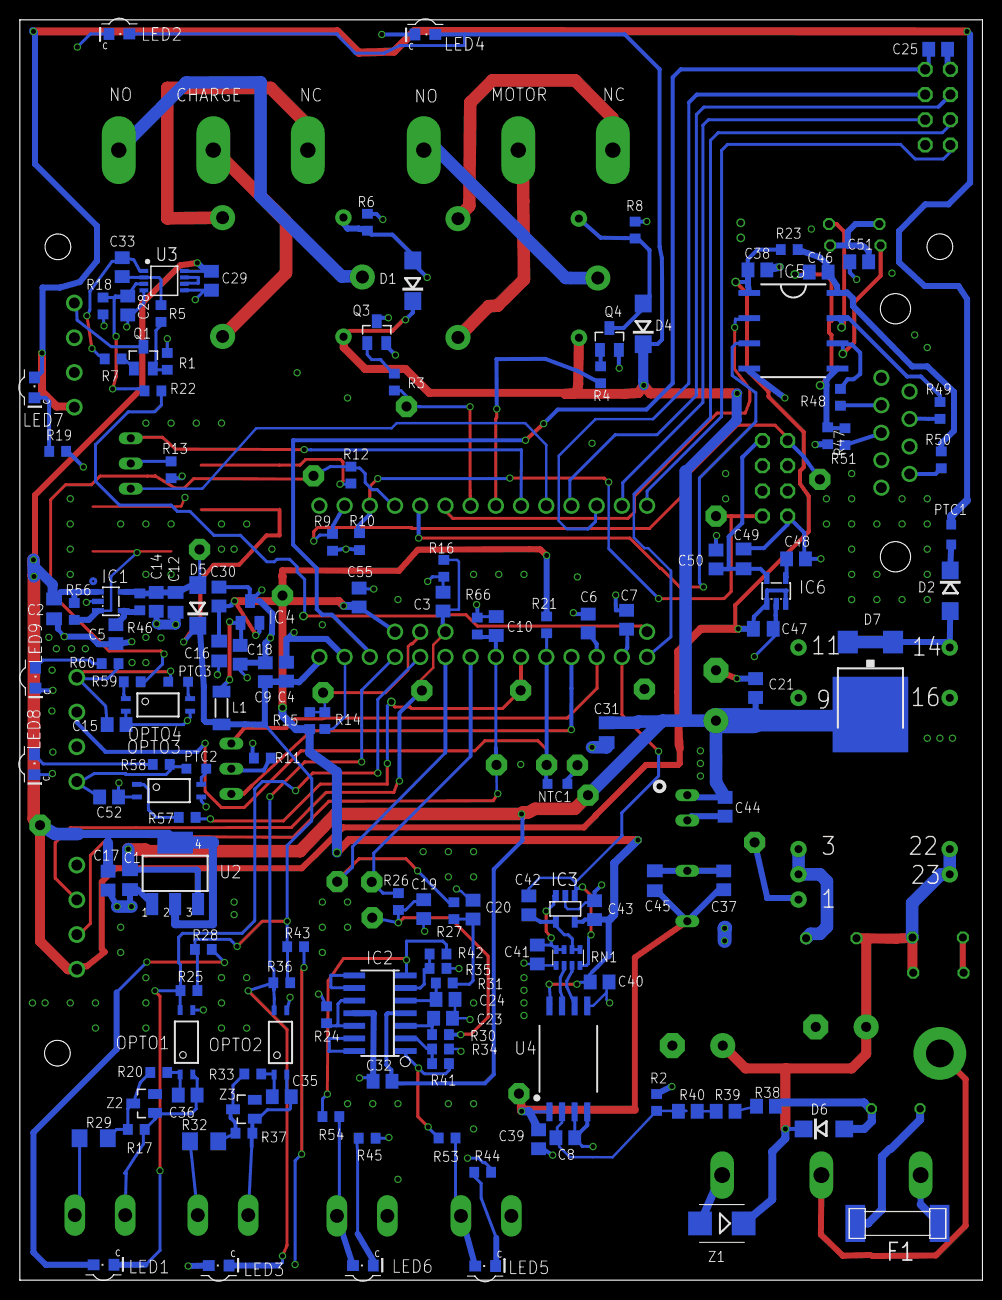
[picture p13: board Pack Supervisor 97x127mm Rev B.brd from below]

Board: 4 copper layers, 97.0 x 127.0 mm, 206 parts (147 on the bottom side), 122 nets.

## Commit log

2019-10-07 Add files via upload
    Files for first tested version of DKblock Pack Supervisor board
2019-11-20 Update readme with picture of PCB incl. features
2020-03-16 Kicad update
2021-03-27 New V2 radio board using CC1310 for more nodes and better comms
2022-08-23 In testing- Supervisor board with LCD driver AND interface to I2C fuel gauge chip
